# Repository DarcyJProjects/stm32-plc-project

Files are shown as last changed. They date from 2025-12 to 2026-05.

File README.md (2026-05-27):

# Industrial Automation Embedded Controller

### Introduction

This project was a deep dive into 4-layer PCBs, galvanic isolation, strict EMI filtering, and mixed-signal design with the goal to create a robust, industrial-style controller from scratch.

Built around an STM32 Cortex-M4, this embedded controller handles galvanically isolated field I/O using a custom DMA-driven MODBUS RTU stack. It also features a "no-code" automation engine, letting you configure logic remotely via a web panel.

I've implemented several hardware features including an RTC with battery backup, HMI OLED, microSD logging, an EEPROM, efficient multi-stage power distribution & conversion with real time power monitoring, as well as many protection features.

The entire ecosystem - the custom PCB, schematics, firmware, and the web panel - is completely open-source right here, so feel free to look into it and see how it works!

#### Datasheet: Read the full datasheet [here](https://github.com/DarcyJProjects/embedded-controller/blob/main/Documentation/datasheet/datasheet.pdf).

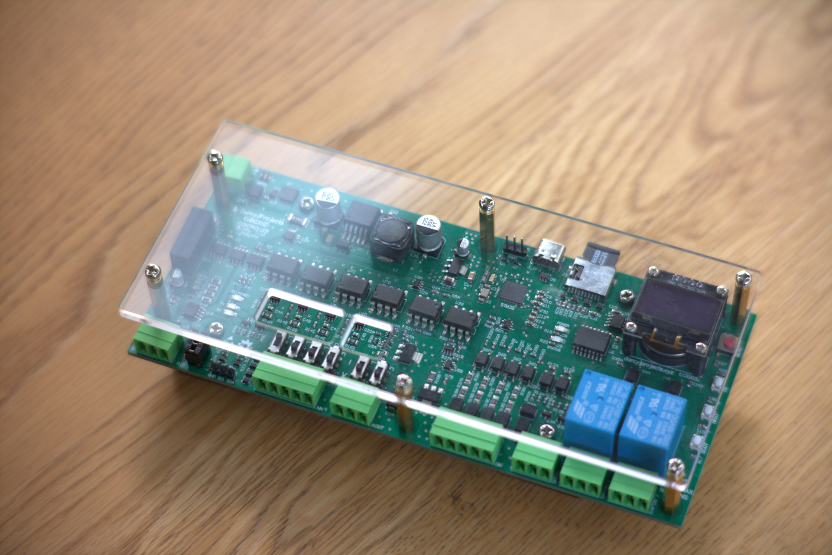
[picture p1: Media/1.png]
IMG: Main


<p>
  This project is open source hardware under the <strong>CERN Open Hardware Licence Version 2 - Strongly Reciprocal (CERN-OHL-S v2)</strong>.
</p>
Open Source Hardware Logo

The editable hardware source files are provided so that the design can be studied, modified, and manufactured in accordance with the licence.

⚖️**Disclaimer:** *This hardware is a personal engineering project created solely for **educational purposes and skill development**. While it explores industrial design techniques, it has not been tested against or certified for any specific industrial standards (e.g., IEC, UL, CE). It is provided ”AS IS” without warranty. For full licence details, design files, and terms of use, please see the **[licence section of this document](#-licence)**.*

---

## 📑 Table of Contents

* 📷 [Demo](#-demo)

* 🎛 [Features and Specifications](#-features-and-specifications)

* ⚡[How It Works](#-how-it-works)

* 🧠 [Why I Built This](#-why-i-built-this)

* 🛠️ [Getting Started](#%EF%B8%8F-getting-started)

* 📂 [Repo Structure](#-repo-structure)

* 📜 [Licence](#-licence)

* ⚠️ [Safety Disclaimer](#-safety-disclaimer)

* 🔗 [Acknowledgements](#-acknowledgements)

* 💬 [Feedback & Contributions](#-feedback--contributions)

---

## 📷 Demo

For the demo, I mounted the controller on a DIN rail and wired it into a small irrigation-style test rig. The goal was to demonstrate as many parts of the board as possible, including relay outputs, digital inputs, analogue voltage signals, 4-20 mA current loops, and MODBUS-based monitoring/control.

Coming soon...

---

## 🎛 Features and Specifications

I tried to pack a wide range of industrial-style hardware and firmware features into this controller so I could learn as much as possible across the realms of PCB design, embedded firmware, power electronics, isolation, and automation protocols.

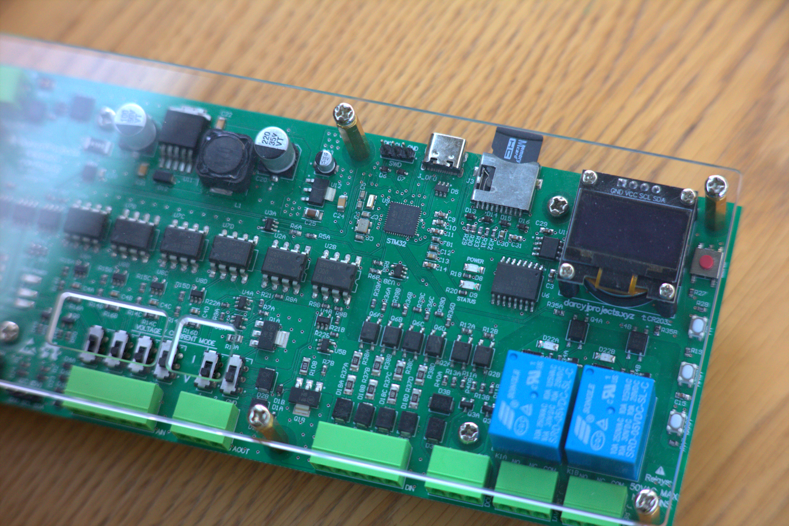
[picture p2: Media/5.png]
IMG: PCB


### **Core Specifications:**

- **Core:** STM32G431 Cortex-M4 MCU running at up to 170 MHz
- **Power input:** 7–28 V DC input range
- **PCB:** Custom 4-layer PCB with separated logic and field domains
- **Protection:** Reverse polarity protection, over-current protection, TVS protection, and ESD protection
- **Isolation:** Galvanic isolation between the logic side and field-side interfaces
- **Memory:** 4 KB EEPROM with CRC-backed configuration and automation rule storage
- **Connectivity:** Isolated RS485 for MODBUS RTU, plus USB-C for DFU flashing and serial debugging
- **Control:** Web panel with custom "no-code" automation rules and MODBUS register access
- **Local interface:** OLED display, tactile buttons, status LEDs, and hardware mode switches, on-board configuration factory reset
- **Expansion:** Isolated I²C header for supported field-side peripherals

### Isolated Field I/O:

- **4x Analogue inputs**
  
  - 12-bit measurement
  - Each configurable for 0–5 Vor 4–20 mA operation

- **2x Analogue outputs**
  
  - 12-bit output
  - Each configurable for 0–5 V voltage output or 4–20 mA current-loop operation

- **4x Digital inputs**
  
  - Designed for 24 V DC signalling

- **2x Digital outputs**
  
  - Low-side sinking outputs for 24 V DC loads

- **2x Relay outputs**
  
  - Intended for ELV switching only
  - Rated in the datasheet for 30 V DC / 50 V AC application limits

- **Isolated I²C expansion header**
  
  - Allows supported external devices to be mapped into the MODBUS register space with custom firmware drivers

### Power:

- Buck Converter for High Efficiency 24 V to 5 V conversion
- Linear Regulator for a clean 3.3 V supply to the MCU
- Switching Isolation Power Supply to power the field side circuitry
- PPTC Fuses, "Ideal Diode" Reverse Polarity Protected Input

### On Board HMI:

- 0.96" OLED display
- 4x tactile buttons for menu navigation, reset, DFU entry, and factory reset
- Status LEDs for power, isolated power, communication, relay state, and general status
- Hardware mode switches for analogue current/voltage configuration

### Overall Block Diagram:

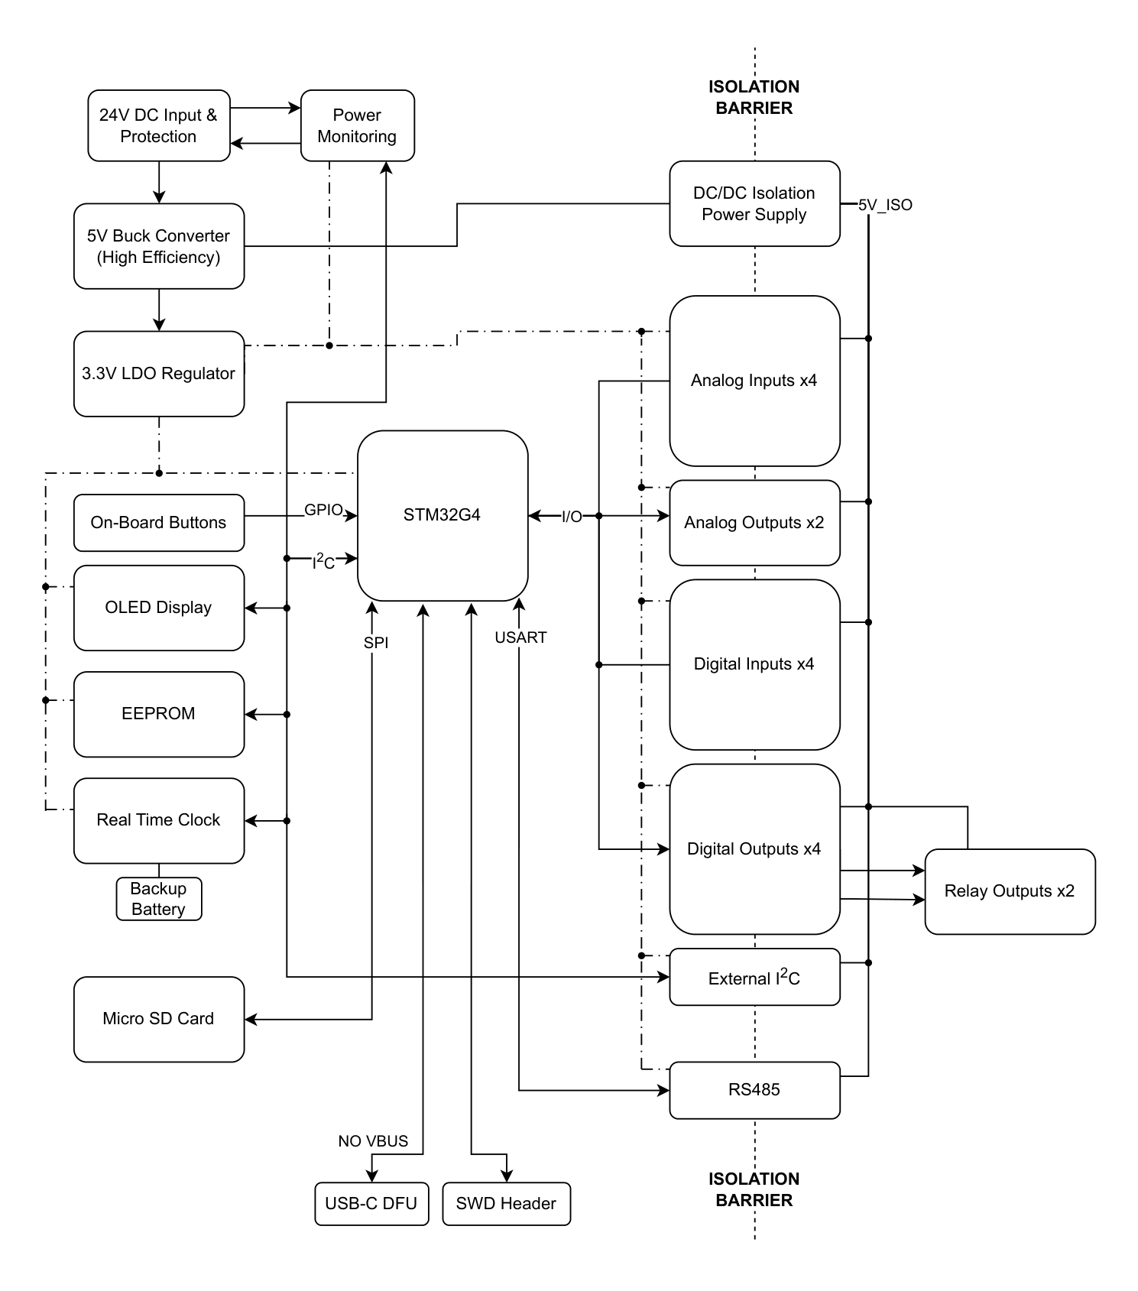
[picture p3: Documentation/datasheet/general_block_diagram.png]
IMG: Block diagram


### Power Supply Block Diagram:

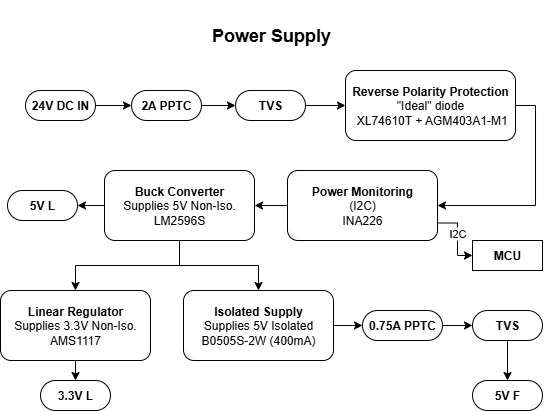
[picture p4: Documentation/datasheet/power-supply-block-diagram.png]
IMG: Power Supply Block Diagram


---

## ⚡ How It Works

The controller is split into two main electrical domains:

1. **Logic Domain:** STM32G4 MCU, EEPROM, OLED, RTC, buttons, USB-C DFU, isolated signals coming from the I/O isolators, etc.

2. **Field Domain:** I/O Inputs and Outputs, Relays, RS485, Isolated I²C expansion header

These two domains are separated by a galvanic isolation barrier. If you look at the PCB, you can actually see a moat separating the two sides copper pours.

The field side is powered through an isolated 5V DC/DC converter, and the signals that cross the barrier use appropriate isolators depending on the interface (capacitive, optical, etc).

### MODBUS register model

The firmware exposes the controller's I/O through a MODBUS register map:

- **Discrete inputs** for digital input states
- **Coils** for digital outputs and relay outputs
- **Input registers** for analogue input readings
- **Holding registers** for analogue output setpoints

There are also **virtual registers**, which can be created dynamically and used as intermediate values in the automation logic. This is useful for when you need to link many rules together for more complex automation logic.

### Custom automation engine

One of the main firmware features is the local automation engine. Instead of reflashing the STM32 every time you want to update its configuration or more importantly its automation logic, rules can be configured directly over MODBUS using custom vendor-defined (that's me!) function codes.

The idea is to make the board behave a little more like a tiny configurable PLC. A rule can read an input, compare a value, update an output, or write to a virtual register. Once configured, the STM32 runs the logic locally.

### Hybrid MODBUS master/slave concept

The firmware is also designed around a hybrid MODBUS architecture allowing the controller to act as both a master and slave at the same time. The controller can report data to an upstream system while also communicating with downstream MODBUS devices.

For instance, [I reverse engineered an RS485 SHT30 sensor](https://darcyjprojects.xyz/index.php/2025/07/08/reverse-engineering-a-cheap-sht30-rs485-modbus-sensor/) used for reading temperature and humidity. By connecting this to the RS485 line of the embedded controller, it can read from the sensor over MODBUS (as a master to the slave sensor) while also reporting information requested back to the web panel (as a slave to the master web panel). 

This was mainly an experiment in building something more flexible than a fixed slave board, while still keeping the system simple enough to understand and debug.

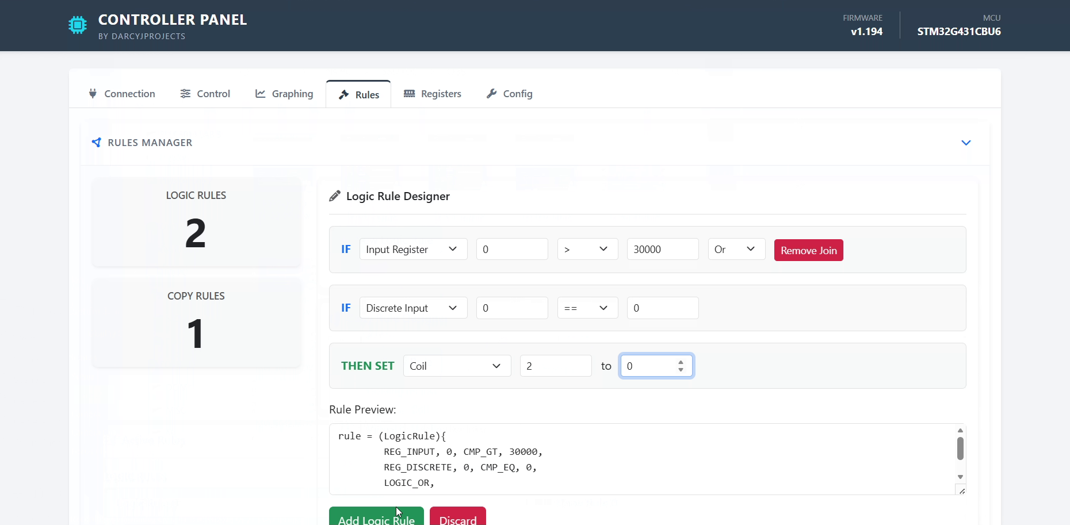
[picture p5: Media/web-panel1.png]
IMG: Web Panel


---

## 🧠 Why I Built This

This project was a major undertaking compared to my earlier electronics projects, integrating mixed signal design, complex isolation barriers, and low level C protocol implementation. I wanted to build something that forced me to deal with more realistic embedded hardware problems, relevant to industrial, mining, manufacturing and remote monitoring environments.

### What I learnt: hardware

- 4-layer PCB design
- Altium Designer workflow
- Mixed-signal PCB layout
- Analogue and digital galvanic isolation
- Isolated power supply design
- 24 V field input and output circuitry
- 4–20 mA current-loop inputs and outputs
- RS485 physical-layer design, termination, and biasing
- Relay output design and low-side switching
- Protection circuitry using PPTC fuses, TVS diodes, and MOSFET-based reverse polarity protection
- Rail-to-rail op-amp circuits for buffering, scaling, and signal conditioning
- Debugging real PCB mistakes using trace cuts, enamel wire, and a lot of patience
- Parasitic impedance and what it does to buck converters!

### **What I learnt: Software**

- STM32CubeIDE and STM32G4 firmware development
- Writing a MODBUS RTU stack from scratch
- Using DMA so communication does not block the CPU
- Building drivers for EEPROMs, RTCs, OLEDs, and other peripherals
- Storing configuration data with CRC checks
- Designing a small rule engine for local automation logic
- Mapping physical and virtual I/O into a MODBUS register model
- Building a Node.js web panel to configure and monitor an embedded device
- How to use LaTeX to write documentation

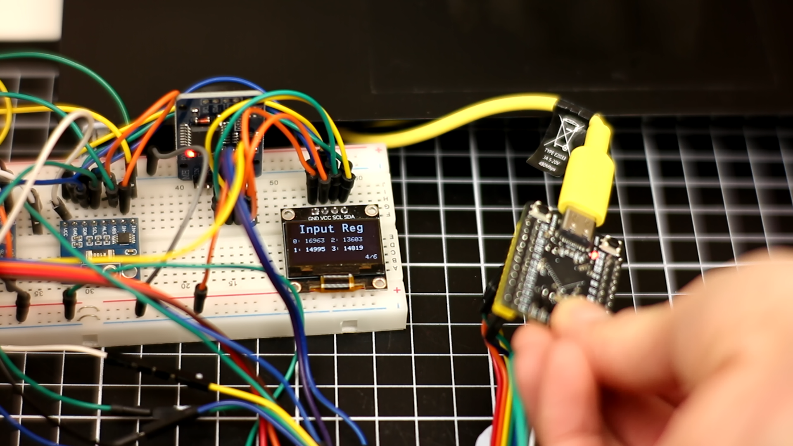
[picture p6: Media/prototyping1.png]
IMG: Prototyping


---

## 🛠️ Getting Started

> **Note:** This project is not a polished commercial product or a beginner-friendly kit. It is a learning project and should be treated carefully, especially when connecting external power supplies, field wiring, or loads.

### Hardware

Before powering the board:

1. Inspect the PCB for solder bridges, assembly mistakes, damaged connectors, or incorrect component values.
2. Check the analogue input/output mode switches before connecting sensors or actuators.
3. Confirm the input supply is within the supported DC range.
4. Use a current-limited bench supply for first power-up.
5. Do not connect mains voltage or safety-critical loads.
6. Check the datasheet before connecting external devices.

### Firmware

The STM32 firmware project is intended to be opened in STM32CubeIDE.

Typical workflow:

1. Open the firmware project
2. Build the project in STM32CubeIDE.
3. Flash the board using USB DFU (hold down BOOT0 and press NRST while powered to enter DFU mode)
4. Connect over serial/MODBUS for debugging or configuration.

### Web panel

The web panel is intended to run locally and communicate with the controller over a USB/serial MODBUS connection.

```bash
cd "Web Panel"
npm install
npm start
```

Then open the local address shown in the terminal in a web browser. You will need an RS485 to USB-Serial converter so that you can select a COM port to communicate with the embedded controller.

---

## 📂 Repo Structure

```text
stm32-plc-project/
├── Documentation/              # Datasheet, drawings
├── Firmware/                   # STM32CubeIDE firmware project
├── Hardware/                   # Altium Designer project: PCB design files, schematics
├── Web Panel/                  # Node.js web configuration panel
├── Media/                      # Photos, renders, screenshots, and demo images
├── LICENCE-CERN-OHL-S-2.0.txt  # CERN-OHL-S v2 licence text for hardware
├── LICENCE-MIT.txt             # MIT licence text for software
└── README.md                   # this file!
```

---

## 📜 Licence

This repository contains both hardware design files and software.

### Hardware

The hardware design files are licenced under the **CERN Open Hardware Licence Version 2 - Strongly Reciprocal (CERN-OHL-S v2)**.

This applies to the PCB design files, schematics, hardware source files, mechanical drawings, and other files required to study, modify, manufacture, and distribute the hardware design.

You are free to:

- **Study** and **modify** the design
- **Make** your own copies
- **Distribute** modified versions, as long as you follow the licence terms

In general, the strongly reciprocal licence means that modified versions of the covered hardware design must also be shared under the same licence, with attribution and source files provided.

For the full legal terms, see [LICENCE-CERN-OHL-S-2.0.txt](https://github.com/DarcyJProjects/embedded-controller/blob/main/LICENCE-CERN-OHL-S-2.0.txt).

### Firmware and Software

Unless otherwise stated, the firmware and software in this repository are licenced under the **MIT Licence**.

This applies to the STM32 firmware and the web configuration panel.

For the full legal terms, see [LICENCE-MIT.txt](https://github.com/DarcyJProjects/embedded-controller/blob/main/LICENCE-MIT.txt).

### Third-Party Code and Resources

Some parts of this project make use of third-party open-source code and resources. These remain under their original licences and are acknowledged in the [Acknowledgements](#-acknowledgements) section.

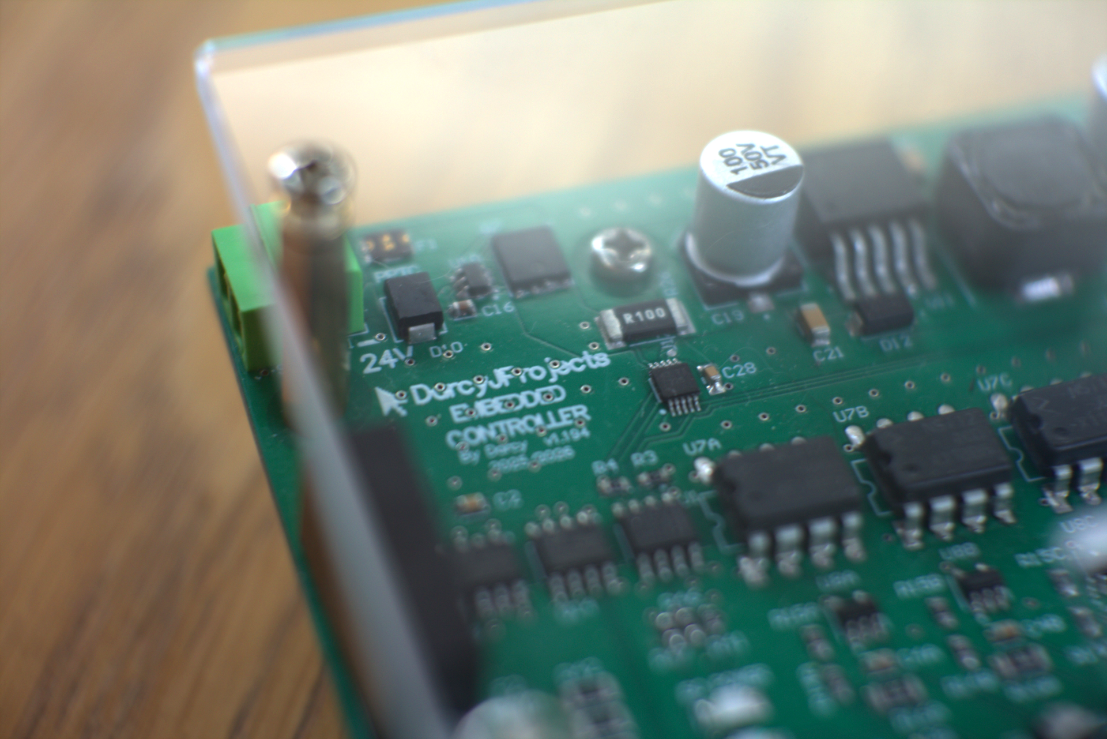
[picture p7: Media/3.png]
IMG: Close up


---

## ⚠️ Safety Disclaimer

This hardware is a personal engineering project created solely for educational purposes, experimentation, and skill development.  

Although it uses industrial-style design techniques, it has **not** been tested, approved, certified, or validated against industrial, safety, EMC, electrical, environmental, functional safety, or regulatory standards, including IEC, UL, CE, RCM, or any similar certification scheme.  

**LIMITATION OF LIABILITY:**

**THIS PROJECT IS PROVIDED "AS IS", WITHOUT WARRANTY OF ANY KIND, EXPRESS OR IMPLIED. TO THE MAXIMUM EXTENT PERMITTED BY LAW, THE COPYRIGHT HOLDER ACCEPTS NO LIABILITY FOR ANY DAMAGE, INJURY, DEATH, LOSS, NON-COMPLIANCE, EQUIPMENT FAILURE, DATA LOSS, BUSINESS INTERRUPTION, OR ANY OTHER ISSUE RESULTING FROM THE USE, MODIFICATION, MANUFACTURE, ASSEMBLY, DISTRIBUTION, OR ATTEMPTED DEPLOYMENT OF THIS DESIGN.**

Do **not** use this project in:  

- real industrial installations  
- safety-critical systems  
- mains-voltage systems  
- life-support, medical, automotive, aviation, mining, or hazardous environments  
- commercial products without proper engineering review, testing, certification, and regulatory approval  
- any system where failure could cause injury, property damage, environmental harm, financial loss, or unsafe operation  

Anyone using, modifying, manufacturing, or testing this design does so entirely at their own risk and is responsible for ensuring compliance with all applicable laws, standards, and safety requirements.

---

## 🔗 Acknowledgements

- The datasheet for this project was created using the [LaTeX Datasheet Template by Petteri Aimonen](https://github.com/PetteriAimonen/latex-datasheet-template), which is licenced under the LPPL-1.3c licence.

- The firmware directly uses the [stm32-ssd1306 OLED display driver by afiskon](https://github.com/afiskon/stm32-ssd1306) for the SSD1306-based OLED display, which is licenced under the MIT licence.

- The MicroSD / FatFS implementation was helped by this tutorial kiwih: [An SD card over SPI using STM32CubeIDE and FatFS](https://01001000.xyz/2020-08-09-Tutorial-STM32CubeIDE-SD-card/).

- Some parts of the firmware were written early in the project while the hardware was still being tested on breadboards. I have tried to acknowledge all external resources used, but if I have missed anything, please let me know and I will be happy to add the appropriate credit.

---

### 💬 Feedback & Contributions

Feel free to fork, share, and build your own!

If you build one, adapt part of the design, or use it to help with one of your own projects, I would love to see it - tag me on [LinkedIn](https://www.linkedin.com/in/darcywdjohnson/).

---

🔧 Darcy @ [www.darcyjprojects.xyz](https://www.darcyjprojects.xyz)

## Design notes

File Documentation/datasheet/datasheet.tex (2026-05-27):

%% STM32 Industrial Controller Datasheet
%% Customized for DarcyJProjects

\documentclass[10pt]{datasheet}

% Standard packages
\usepackage[utf8]{inputenc}
\usepackage[english]{babel}
\usepackage{graphicx} % Needed for inserting photos/block diagrams
\usepackage{tabularx} % Better tables
\usepackage{float} % Keep things where they should be
\usepackage{enumitem}
% Allows absolute positioning of text (for the version stamp)
\usepackage[absolute]{textpos}

% Document Meta-Data
\title{STM32G4 Embedded Industrial Controller}
\author{DarcyJProjects}
\date{February 2026}
\revision{Rev 1.0}
\companylogo{
    % Negative value (-0.2\height) pushes the image DOWN by 20% of its own height
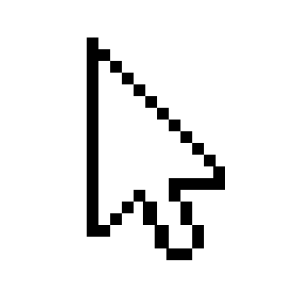
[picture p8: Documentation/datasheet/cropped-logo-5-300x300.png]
    \raisebox{-0.22\height}{}
    \hspace{0cm} % Adds a small gap between logo and text
    \Huge \textbf{DarcyJProjects}
} % Simple text logo for now

\begin{document}

% --- HARDWARE VERSION STAMP ---
% {5cm} is the width of the box
% (15cm, 1cm) are the X, Y coordinates from the top-left of the page
% Adjust 15cm to move it Left/Right, Adjust 1cm to move it Up/Down
\begin{textblock*}{5cm}(15cm, 2.5cm) 
    \raggedleft % Align text to the right
    \small 
    \textbf{Hardware Ver:} v1.194
\end{textblock*}

\maketitle

\section{Features}
\begin{itemize}[leftmargin=*, itemsep=2pt, topsep=0pt]
    \item \textbf{Core:} STM32G431 Cortex-M4 MCU @ 170MHz
    \item \textbf{Power:} 12V-28V DC (Rev. Polarity, OCP, TVS)
    \item \textbf{Isolation \& Protection:} 1 kV Galvanic Isolation, ESD Protection up to 30 kV
    
    % CONDENSING STRATEGY: Use a paragraph style for the big lists.
    % Notice how we just list them with commas instead of new bullets.
    \item \textbf{Field I/O (All Isolated):}
    4x Analog Inputs (12-bit, 4-20mA/0-5V),
    2x Analog Outputs (12-bit, 4-20mA/0-5V),
    4x Digital Inputs (24V),
    2x Digital Outputs (24V),
    2x Relays (10A / 30VDC, ELV 50VAC),
    Isolated $I^2$C Header.

    \item \textbf{On-Board HMI:} 
    0.96" OLED Display, 
    4x Tactile Buttons, 
    5x Status LEDs, 
    6x Hardware Mode Switches (Analog Current/Voltage Mode Configuration).

    \item \textbf{Memory:} 4KB EEPROM with CRC (Stores Configuration \& Automation Rules)

    \item \textbf{Connectivity:}
    Isolated RS485 (MODBUS RTU Master/Slave);
    USB-C (DFU Flashing \& Serial Debug)

    \item \textbf{Reliability:} 4-Layer PCB with Isolation Barrier, PPTC Fuses, TVS Protection.
    \item \textbf{Control:} Web Panel with custom "No-Code" automation engine; Full MODBUS RTU support for SCADA integration.
\end{itemize}

\section{Example Demonstration Use Cases}
\begin{itemize}[leftmargin=*, itemsep=2pt, topsep=0pt]
    \item \textbf{Industrial Sensor Node:} Aggregation of voltage or 4-20mA process signals (pressure, flow, level) to MODBUS RTU.
    \item \textbf{Distributed I/O Expansion:} Cost-effective relay control and status monitoring for existing SCADA networks.
    \item \textbf{Hybrid Edge Controller:} Autonomous control of downstream MODBUS slaves (e.g., VFDs, remote sensors) while simultaneously reporting status to an upstream SCADA system.
    \item \textbf{Embedded Logic Prototyping:} Development platform for custom control loops and automation logic using the STM32G4.
\end{itemize}

% --- SECTION 3: VISUALS ---
% \vfill\break % Force column break so images sit nicely on the right

\begin{figure}[h]
    \centering
    % REPLACE 'example-image' with your actual filename (e.g., board_photo.png)
    % You can upload files to Overleaf using the upload button on the left.
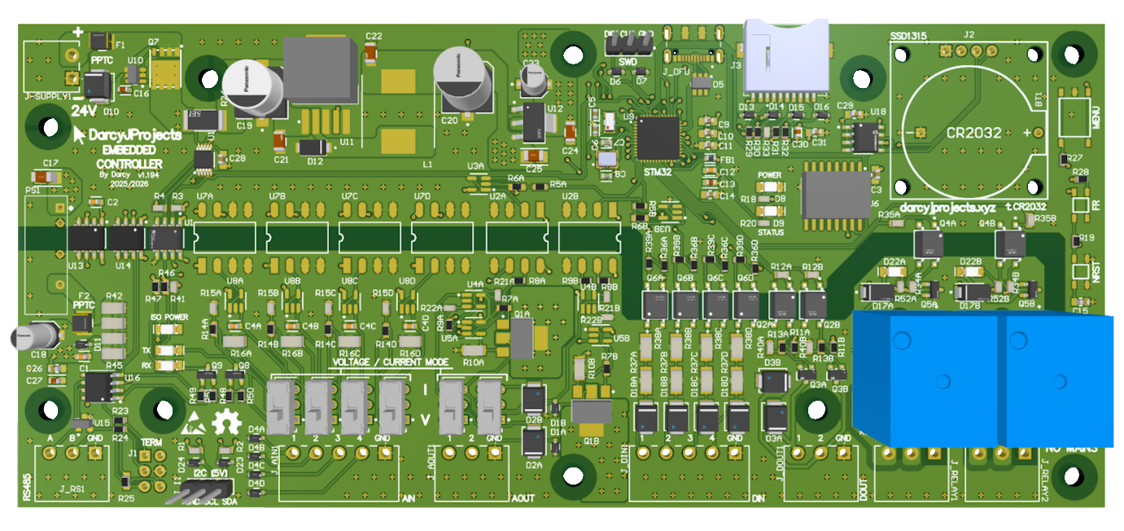
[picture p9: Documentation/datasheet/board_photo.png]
     
    \caption{Board Top View}
\end{figure}

%\begin{figure}[h]
%    \centering
    % REPLACE 'example-image' with your block diagram
%    \includegraphics[width=0.8\linewidth]{example-image}
%    \caption{System Block Diagram}
%\end{figure}

% --- SECTION 2: DESCRIPTION ---
\section{General Description}
The \textbf{DJP-G431-EIC} is an educational embedded controller inspired by industrial I/O and PLC-style design practices. Built around the high-performance STM32G4 series, it features a high-efficiency 24V buck converter and \textbf{full galvanic isolation} on all field interfaces, ensuring system stability in noisy environments.

Unique to this controller is a \textbf{Hybrid Master-Slave} configuration handled by a custom \textbf{DMA-driven MODBUS RTU stack}. This allows the board to autonomously control downstream devices while simultaneously reporting to an upstream SCADA system or Web Panel. An on-board OLED display with burn-in protection provides local feedback on system status and configuration.

For logic control, the board natively supports a custom \textbf{Rule-Based Automation Engine}. This system is fully programmable over MODBUS using the Node.js Web Panel or manually with the vendor-defined functions, allowing for remote "No-Code" logic configuration without the need to reflash firmware.

% The "Research Purpose" Qualifier
\vspace{1em}
\begin{center}
\fbox{\parbox{0.95\linewidth}{
    \centering
    \scriptsize
    \textit{\textbf{DISCLAIMER:} This hardware is a personal engineering project created solely for \textbf{educational purposes and skill development}. While it explores industrial design techniques, it has \textbf{not} been tested against or certified for any specific industrial standards (e.g., IEC, UL, CE). It is provided "AS IS" without warranty.}
    
    \vspace{0.3em} % Tiny gap
    \textit{For full licence details, design files, and terms of use, please refer to the project repository at \textbf{github.com/DarcyJProjects}.}
}}
\end{center}

% Switch to single column for the big data tables
\onecolumn
\clearpage
\raggedbottom

\section{System Architecture}
The internal architecture of the DJP-G431-EIC is divided into two galvanically isolated domains: the \textbf{Logic Domain} (MCU, Main Power Supply, etc.) and the \textbf{Field Domain} (Field I/O, RS485, etc.). 

The following block diagram illustrates the power distribution path, isolation barriers, and internal peripheral connections. A physical separation width is maintained along the isolation barrier on the PCB utilising different electrical isolation methods (capacitive, optical, etc.), depending on the signal.

% BLOCK DIAGRAM
\begin{figure}[H]
    \centering
    % Reduced width slightly to 0.85 to ensure everything fits
     
    \caption{System Block Diagram showing Power Architecture and Galvanic Isolation.}
    \label{fig:general_block_diagram}
\end{figure}

\section{Electrical Specifications}
Conditions: $V_{IN} = 24V$, $T_A = 25^{\circ}C$ unless otherwise noted.

\begin{table}[H]
\caption{Isolation \& Protection Characteristics}
\begin{tabularx}{\textwidth}{l | c | c | X}
    \thickhline
    \textbf{Parameter} & \textbf{Symbol} & \textbf{Value} & \textbf{Conditions} \\
    \hline
    \multicolumn{4}{l}{\textit{\textbf{Galvanic Isolation}}} \\
    \hline
    \textbf{System Isolation} & $V_{ISO\_SYS}$ & \textbf{1000 VDC} & \textbf{Limited by DC/DC Power Supply} \\
    Data Channel Rating & $V_{ISO\_DAT}$ & 3750 Vrms & Component Rating (Isolators Only) \\
    Isolation Capacitance & $C_{ISO}$ & $\sim$40 pF & Barrier Capacitance (Typical) \\
    \hline
    \multicolumn{4}{l}{\textit{\textbf{ESD Protection}}} \\
    \hline
    \textbf{General I/O \& Power} & $V_{ESD\_GEN}$ & $\pm$30 kV & \textbf{IEC 61000-4-2} (Air \& Contact) \\
    \multicolumn{4}{l}{\textit{\footnotesize (Includes: Power In, Digital I/O, Analog I/O, SD Card, SWD)}} \\
    \hline
    \textbf{Comm. Interfaces} & $V_{ESD\_COM}$ & $\pm$15 kV & \textbf{IEC 61000-4-2} (Air) \\
     & & $\pm$8 kV & \textbf{IEC 61000-4-2} (Contact) \\
    \multicolumn{4}{l}{\textit{\footnotesize (Includes: RS485, USB DFU)}} \\
    \hline
    \textbf{I2C Expansion} & $V_{ESD\_I2C}$ & $\pm$4 kV & \textbf{HBM} (ISO1540 Native Rating) \\
    \hline
    \multicolumn{4}{l}{\textit{\textbf{EFT Immunity}}} \\
    \hline
    Power \& Field I/O & $V_{EFT}$ & 4 kV & \textbf{IEC 61000-4-4} (Level 4) \\
    \thickhline
\end{tabularx}
\end{table}

\begin{table}[H]
\caption{Over-Current Protection (PPTC Resettable Fuses)}
\begin{tabularx}{\textwidth}{l | c | c | c | X}
    \thickhline
    \textbf{Protected Rail} & \textbf{Hold} ($I_{HOLD}$) & \textbf{Trip} ($I_{TRIP}$) & \textbf{Max V} & \textbf{Notes} \\
    \hline
    Main Power Input ($V_{IN}$) & 2 A & $\sim$2x the hold  & 30 V & Protects entire board \\
    5V\_ISO & 750 mA & $\sim$2x the hold & 6 V & Protects B0505S isolated DC/DC \\
    \thickhline
\end{tabularx}
\begin{tablenotes}
\footnotesize
\item \textbf{Note:} Fuses are self-resetting. To reset a tripped fuse, remove the fault and cycle power for $>10$ seconds.
\end{tablenotes}
\end{table}

\begin{table}[h]
\begin{threeparttable}
\caption{DC Characteristics}
\begin{tabularx}{\textwidth}{l | c | c c c | c | X}
    \thickhline
    \textbf{Parameter} & \textbf{Symbol} & \textbf{Min.} & \textbf{Typ.} & \textbf{Max.} & \textbf{Unit} & \textbf{Comments} \\
    \hline
    \multicolumn{7}{l}{\textbf{Power Supply}} \\
    \hline
    Supply Voltage      & $V_{IN}$   & 12  & 24  & 28  & V  & Operating Range \\
    Supply Current      & $I_{IN}$   & -   & 90  & 150 & mA & Idle vs. Relays Active @ $V_{IN}$=24 V \\
    \hline
    \multicolumn{7}{l}{\textbf{Digital Inputs}} \\
    \hline
    Input Voltage High  & $V_{IH}$   & 1.5  & 24  & 28  & V  & Logic "1" Threshold \\
    Input Voltage Low   & $V_{IL}$   & 0  & 0   & 1.3  & V  & Logic "0" Threshold \\
    Input Current       & $I_{DIN}$  & -   & 11.4   & 14.9  & mA & @ 24V (Typ) / 28V (Max) \\
    \hline
    \multicolumn{7}{l}{\textbf{Digital Outputs}} \\
    \hline
    Cont. Sink Current  & $I_{DOUT}$ & -   & -   & 500 & mA & \textbf{Sinking} Per Channel \\
    Output Voltage Drop & $V_{DROP}$ & -   & 10 & 16 & mV  & @ 500mA Load \\
    \hline
    \multicolumn{7}{l}{\textbf{Digital Outputs (Relays)}} \\
    \hline
    Switching Voltage (DC)   & $V_{SW}$   & -   & 24  & 30 & V  & DC Voltage  \\
    Switching Voltage (AC)   & $V_{SW}$   & -   & 24  & 50 & VAC  & AC Voltage  \\
    Switching Current   & $I_{SW}$   & -   & -   & 10  & A  & Max Resistive Load \\
    Contact Resistance  & $R_{CONT}$ & -   & - & 100   & m$\Omega$ & Initial value \\
    \hline
    \multicolumn{7}{l}{\textbf{Analog Inputs (12-Bit)}} \\
    \hline
    Input Impedance (V) & $R_{IN(V)}$& - & 49   & -   & k$\Omega$ & 0-5V Mode \\
    Input Impedance (I) & $R_{IN(I)}$& -   & 10 & -   & $\Omega$ & 4-20mA Mode \\
    \hline
    \multicolumn{7}{l}{\textbf{Analog Outputs (12-Bit)}} \\
    \hline
    Output Voltage      & $V_{OUT}$  & 0   & -   & 5   & V  & 0-5V Mode -- \textbf{Sourcing} (Active) \\
    % Source Current      & $I_{SRC}$  & -   & -   & XX  & mA & 0-5V Mode -- Max drive \\
    \hline
    % Current Sink Range\tnote{1}  & $I_{SNK}$  & X   & -   & XX  & mA & 4-20mA Mode -- \textbf{Sinking} (Passive) \\
    Max Loop Voltage\tnote{3}    & $V_{LOOP}$ & 12  & 24  & 30  & V  & 4-20mA Mode -- Ext. Loop Supply \\
    Max Loop Resistance & $R_{LOOP}$ & 300 & 900 & 1075 & $\Omega$ & @ 12V / 24V / 30V Loop Voltage \\
    \hline
    \multicolumn{7}{l}{\textbf{RS485 Interface}} \\
    \hline
    Bus Voltage Range\tnote{2}   & $V_{BUS}$  & -7  & -   & 12  & V  & Common Mode Range (A/B) \\
    Input Impedance     & $R_{IN}$   & 12  & -   & -   & k$\Omega$ & 1 Unit Load (Max 32 Nodes) \\
    \hline
    \multicolumn{7}{l}{\textbf{External $I^2C$ Expansion Header}} \\
    \hline
    Field Signal Voltages\tnote{2}      & $V_{SDA2}, V_{SCL2}$  & 0 & - & 5.0 & V  & Field Signal Voltages \\
    Pull-Up Resistance  & $R_{PU}$   & 4.4   & 4.7 & 5.0   & k$\Omega$ & On-Board $I^2C$ Field Pull-ups \\
    \thickhline
\end{tabularx}
\begin{tablenotes}
\footnotesize
% The \tnote{1} connects to the superscript 1 in the table
\item[1] \textbf{Note:} The exact 4mA and 20mA setpoints are determined by firmware calibration values. Improper configuration may result in output currents deviating from these nominal targets (e.g. $<4$mA or $>20$mA).
\item[2] Relative to 5V\_ISO\_GND (the GND pin in the field header or connector).
\item[3] \textbf{Important:} The maximum loop voltage drops significantly as the ambient temperature rises. See Absolute Maximum Ratings.
\end{tablenotes}
\end{threeparttable}
\end{table}

\clearpage

\section{Absolute Maximum Ratings}
\begin{table}[H]
\caption{Stress Ratings}
\begin{tabularx}{\textwidth}{l | c | c c | c | X}
    \thickhline
    \textbf{Parameter} & \textbf{Symbol} & \textbf{Min.} & \textbf{Max.} & \textbf{Unit} & \textbf{Comments} \\
    \hline
    \multicolumn{6}{l}{\textbf{Power}} \\
    \hline
    Input Voltage       & $V_{IN\_MAX}$  & 7 & 30 & V & Continuous (Limited by Input PPTC \& TVS) \\
    Max Total Current   & $I_{IN\_MAX}$  & - & 2 & A & Limited by Input PPTC \\
    \hline
    \multicolumn{6}{l}{\textbf{Digital I/O}} \\
    \hline
    DIN Voltage         & $V_{DIN\_MAX}$ & - & 30 & V & Continuous (Thermal Limit of Series Resistors)\\
    \hline
    DOUT Sink Current   & $I_{DOUT\_MAX}$ & - & 3 & A & Continuous (Per Channel) @ $T_A = 85^{\circ}C$\\
    Relay Voltage       & $V_{SW\_MAX(DC)}$ & - & 30 & V & Max DC Contact Switching Voltage \\
    Relay Voltage       & $V_{SW\_MAX(AC)}$ & -  & 50 & VAC & Max AC Contact Switching Voltage \\
    Relay Current       & $I_{REL\_MAX}$ & - & 10 & A & Resistive Load \\
    \hline
    \multicolumn{6}{l}{\textbf{Analog I/O}} \\
    \hline
    AIN Voltage (V-Mode)& $V_{AIN\_MAX(V)}$ & -   & \textbf{5.5} & V & \textbf{Risk of Damage!} (Do not connect 24V) | Continuous (Limited by Input TVS)\\
    AIN Current (I-Mode)& $I_{AIN\_MAX(I)}$ & -   & 140 & mA & Max Loop Current (Shunt Resistor Limit) \\
    \hline
    AOUT Voltage (V-Mode)& $V_{AOUT\_MAX(V)}$ & - & \textbf{5.3} & V & \textbf{Risk of Damage!} (Do not connect 24V) | Max External Voltage applied to pin \\
    AOUT Voltage (I-Mode)& $V_{AOUT\_MAX(I)}$ & - & 26 & V & Max External Loop Voltage (Open Collector) @ $T_A = 85^{\circ}C$ \\
    \hline
    \multicolumn{6}{l}{\textbf{Communication Interfaces}} \\
    \hline
    RS485 Bus Voltage In   & $V_{485\_IN\_ABS}$ & -8 & +12.5 & V & Max voltage on A/B pins before damage \\
    RS485 Bus Voltage Out   & $V_{485\_OUT\_ABS}$ & -8 & +12.5 & V & Max voltage from driver to A/B pins \\
    I2C Pin Voltage     & $V_{I2C\_ABS}$ & -0.5 & 5.5 & V & Max voltages on SDA/SCL \\
    \hline
    %\multicolumn{6}{l}{\textbf{Environmental}} \\
    %\hline
    %Storage Temp.       & $T_{STG}$      & -XX & +XX & $^{\circ}$C & Estimation\\
    %Operating Temp.     & $T_{OP}$       & -XX & +XX & $^{\circ}$C & Estimation \\
    %\thickhline
\end{tabularx}
\end{table}

\clearpage

\section{MODBUS Register Map}
% \vspace{-4em} % Pulls the table up by one line height
\begin{table}[H]
\small
\begin{threeparttable}
\caption{Complete Register Map}
\begin{tabularx}{\textwidth}{c | l | c | c | X}
    \thickhline
    \textbf{Addr} & \textbf{Name} & \textbf{Type} & \textbf{Access} & \textbf{Description} \\
    \hline
    \multicolumn{5}{l}{\textit{\textbf{Discrete Inputs (Digital Inputs)}}} \\
    \hline
    0 & DIN\_1 & Bool & R & Digital Input Channel 1 \\
    1 & DIN\_2 & Bool & R & Digital Input Channel 2 \\
    2 & DIN\_3 & Bool & R & Digital Input Channel 3 \\
    3 & DIN\_4 & Bool & R & Digital Input Channel 4 \\
    \hline
    \multicolumn{5}{l}{\textit{\textbf{Coils (Digital Outputs \& Relays)}}} \\
    \hline
    0 & DOUT\_1 & Bool & R/W & Digital Output 1 \\
    1 & DOUT\_2 & Bool & R/W & Digital Output 2 \\
    2 & RELAY\_1 & Bool & R/W & Relay Output 1 \\
    3 & RELAY\_2 & Bool & R/W & Relay Output 2 \\
    \hline
    \multicolumn{5}{l}{\textit{\textbf{Input Registers (Analog Inputs)}}} \\
    \hline
    0 & AIN\_1 & uint16 & R & Analog Input 1 Raw Value \\
    1 & AIN\_2 & uint16 & R & Analog Input 2 Raw Value \\
    2 & AIN\_3 & uint16 & R & Analog Input 3 Raw Value \\
    3 & AIN\_4 & uint16 & R & Analog Input 4 Raw Value \\
    \hline
    \multicolumn{5}{l}{\textit{\textbf{Holding Registers (Analog Outputs)}}} \\
    \hline
    0 & AOUT\_1 & uint16 & R/W & Analog Output 1 Setpoint (0-65535) \\
    1 & AOUT\_2 & uint16 & R/W & Analog Output 2 Setpoint (0-65535) \\
    \thickhline
\end{tabularx}
\begin{tablenotes}
\footnotesize
\item \textbf{Access Key:} R = Read Only, R/W = Read/Write. 
\item \textbf{Function Codes:} Discrete (0x02), Coils (0x01/0x05/0x15), Inputs (0x04), Holding (0x03/0x06/0x16).
\end{tablenotes}
\end{threeparttable}
\end{table}

\subsection{Virtual Registers}
Virtual Registers can be created dynamically to serve as intermediate variables within the automation logic (e.g., linking rules where the 2-condition limit per rule is exceeded).
\begin{itemize}
    \item \textbf{Addressing:} Virtual registers are automatically mapped starting at the address \textit{after} the last physical channel.
    \item \textit{Example:} If the last physical coil is Address 3, the first Virtual Coil will be \textbf{Address 4}.
\end{itemize}

Since Virtual Registers are defined with specific Modbus data types, they can be fully accessed (Read/Write) using standard Modbus function codes.

\clearpage

\subsection{External Expansion ($I^2C$)}
The isolated 5V $I^2C$ header allows external peripherals to be mapped to MODBUS registers. On-board field side 5V\_ISO pull-up resistors (4.7 k$\Omega$) are installed on SCL and SDA so only 5 V-tolerant $I^2C$ devices should be connected directly. Lower-voltage devices may require an external level shifter, such as a PCA9306.
\vspace{1em} \\
\textit{\textbf{Note:} Unlike the Rule Engine, adding new $I^2C$ devices requires custom read/write drivers and a \textbf{firmware update}. Reference implementations for common sensors can be found in the project source code.}

\subsection{Vendor Defined Function Codes}
These proprietary function codes provide access to specialized device capabilities, including the internal logic engine and virtual register management, that are not covered by standard MODBUS definitions.
\textbf{Range:} 0x65--0x73 (Firmware Defined)
\begin{table}[H]
\begin{tabularx}{\textwidth}{c | l | X}
    \thickhline
    \textbf{Code} & \textbf{Name} & \textbf{Description} \\
    \hline
    0x65 & ADD\_RULE & Defines a new automation rule \\
    0x66 & GET\_RULE\_COUNT & Returns the number of automation rules \\
    0x67 & GET\_RULE & Returns the requested automation rule configuration \\
    0x68 & DELETE\_RULE & Deletes the requested automation rule \\
    0x69 & ADD\_VIRTUAL\_REG & Defines a new virtual register \\
    0x6A & READ\_VIRTUAL\_REG & Returns the value of the requested virtual register \\
    0x6B & WRITE\_VIRTUAL\_REG & Write the specified value to the requested virtual register \\
    0x6C & GET\_VIRTUAL\_REG\_COUNT & Returns the number of virtual registers \\
    0x6D & CLEAR\_VIRTUAL\_REG & Deletes all virtual registers. Warning: Do not execute if there are \textbf{any} rules that reference \textbf{any} virtual registers. \\
    0x6E & SET\_RTC & Sets the RTC date and time \\
    0x6F & SET\_HOLDING\_REG\_MODE & Sets the requested holding register to the specified mode (current/voltage) \\
    0x70 & SET\_INPUT\_REG\_MODE & Sets the requested input register to the specified mode (current/voltage) \\
    0x71 & GET\_REG\_MODE & Returns the mode (current/voltage) of the requested register (holding/input) \\
    0x72 & SET\_EMERGENCY\_STOP & Sets the E-STOP button configuration \\
    0x73 & FACTORY\_RESET & Performs a factory reset, resetting the on-board EEPROM to default values \\
    \thickhline
\end{tabularx}
\end{table}

\textbf{Note:} These function codes are firmware-specific and should not be considered MODBUS-standard or interoperable with other devices.

\section{User Interface}

\subsection{Button Functions}
The board features 4 tactile buttons for menu interaction, system recovery, and boot control.

\begin{table}[h]
\begin{tabularx}{\textwidth}{l | l | X}
    \thickhline
    \textbf{Button} & \textbf{Function} & \textbf{Description} \\
    \hline
    \textbf{MENU} & Navigation & Short Press: Next Menu Screen \\
    \textbf{NRST} & System Reset & Short Press: Hardware Reset (Reboots MCU) \\
    \hline
    \textbf{BOOT0 + NRST} & DFU Mode & Hold BOOT0 and short press NRST to enter DFU mode. OLED should indicate that DFU mode has been entered. \\
    \textbf{FR + NRST} & Factory Reset & Hold FR and short press NRST to restore default configuration options on the EEPROM. Further button press instructions will be provided on the OLED. \\
    \textbf{MENU + NRST} & Skip Boot Animations & Hold MENU and short press NRST to skip boot animations when starting. Useful for quick tests during firmware development. \\
     \thickhline
\end{tabularx}
\end{table}

\subsection{LED Indicators}
\begin{table}[H]
\begin{tabularx}{\textwidth}{l | c | X}
    \thickhline
    \textbf{Name} & \textbf{Color} & \textbf{Indication} \\
    \hline
    \textbf{PWR} & Green & 3.3V Logic Domain Power Active \\
    \textbf{STATUS} & Red & General Status Indicator \\
    \textbf{ISO\_PWR} & Green & 5V Isolated Field Domain Power Active \\
    \textbf{RX/TX} & Blue & Modbus RS485 Data Traffic \\
    \textbf{REL1 / REL2} & Red & Relay Coil Energized (Output Active) \\
    \thickhline
\end{tabularx}
\end{table}

\subsection{RS485 Bus Configuration}
The isolated RS485 interface features a 6-pin jumper header (JP\_RS485) to enable line termination and failsafe biasing. These should be configured based on the device's position in the network.

\vspace{0.5em}

\noindent
\begin{minipage}{0.35\textwidth}
    \centering
    \textbf{Jumper Map (Top View)} \\
    \vspace{0.5em}
    % This grid mimics the physical 2x3 header on your PCB
    \begin{tabular}{|c|c|}
        \hline
        \footnotesize \textbf{1} (A) & \footnotesize \textbf{2} (PULL\_UP) \\
        \hline
        \footnotesize \textbf{3} (B) & \footnotesize \textbf{4} (PULL\_DOWN) \\
        \hline
        \footnotesize \textbf{5} (A) & \footnotesize \textbf{6} (TERM. TO B) \\
        \hline
    \end{tabular}
    \\ \vspace{0.5em}
    \footnotesize \textit{Bridge adjacent pins to enable.}
\end{minipage}%
\hfill
\begin{minipage}{0.6\textwidth}
    \textbf{Configuration Settings:}
    \begin{itemize}[noitemsep, leftmargin=1.5em, topsep=0pt]
        \item \textbf{Bias High (Pins 1-2):} Pulls Line A to 5V\_ISO. \textit{Keeps bus logic "1" during idle.}
        \item \textbf{Bias Low (Pins 3-4):} Pulls Line B to 5V\_ISO\_GND. \textit{Keeps bus logic "0" during idle.}
        \item \textbf{Termination (Pins 5-6):} Connects a $120\Omega$ resistor across lines A and B. \textit{Enable only if this device is at the physical end of the bus cable.}
    \end{itemize}
\end{minipage}

\vspace{0.5em}
\noindent \textit{\footnotesize \textbf{Note:} Failsafe biasing (Pins 1-4) is recommended to prevent noise interpretation when the bus is idle, but ensure only ONE device on the bus provides biasing (usually the Master).}

\clearpage

\section{Software Ecosystem}
The DJP-G431-EIC is supported by a comprehensive software suite:
\begin{itemize}
    \item \textbf{Web Configuration Panel:} A Node.js-based dashboard connecting via the USB-Serial bridge. Allows for real-time monitoring of all registers, hardware configuration, and "No-Code" logic automation; all over MODBUS RTU.
    \item \textbf{Automation Engine:} Custom logic engine supporting drop-down based "If-This-Then-That" rules, executed locally on the STM32, programmed over MODBUS vendor functions. A single rule can include up to two conditions, with virtual registers provided as memory to link several rules (\textgreater 2) together.
\end{itemize}

\section{Mechanical \& Installation}

\begin{figure}[h]
    \centering
    % width=1.0\linewidth ensures it fills the column width while maintaining aspect ratio
     
    \caption{Mechanical Dimensions (Units: mm).}
\end{figure}

\clearpage
\section{Safety Disclaimer}

This hardware is a personal engineering project created solely for educational purposes, experimentation, and skill development.

Although it uses industrial-style design techniques, it has \textbf{not} been tested, approved, certified, or validated against industrial, safety, EMC, electrical, environmental, functional safety, or regulatory standards, including IEC, UL, CE, RCM, or any similar certification scheme.

\vspace{1em}

\noindent\textbf{LIMITATION OF LIABILITY:}

\vspace{0.5em}

\noindent\textbf{THIS PROJECT IS PROVIDED ``AS IS'', WITHOUT WARRANTY OF ANY KIND, EXPRESS OR IMPLIED. TO THE MAXIMUM EXTENT PERMITTED BY LAW, THE COPYRIGHT HOLDER ACCEPTS NO LIABILITY FOR ANY DAMAGE, INJURY, DEATH, LOSS, NON-COMPLIANCE, EQUIPMENT FAILURE, DATA LOSS, BUSINESS INTERRUPTION, OR ANY OTHER ISSUE RESULTING FROM THE USE, MODIFICATION, MANUFACTURE, ASSEMBLY, DISTRIBUTION, OR ATTEMPTED DEPLOYMENT OF THIS DESIGN.}

\vspace{1em}

\noindent Do \textbf{not} use this project in:

\begin{itemize}[leftmargin=*, itemsep=2pt, topsep=4pt]
    \item real industrial installations
    \item safety-critical systems
    \item mains-voltage systems
    \item life-support, medical, automotive, aviation, mining, or hazardous environments
    \item commercial products without proper engineering review, testing, certification, and regulatory approval
    \item any system where failure could cause injury, property damage, environmental harm, financial loss, or unsafe operation
\end{itemize}

Anyone using, modifying, manufacturing, or testing this design does so entirely at their own risk and is responsible for ensuring compliance with all applicable laws, standards, and safety requirements.

\end{document}

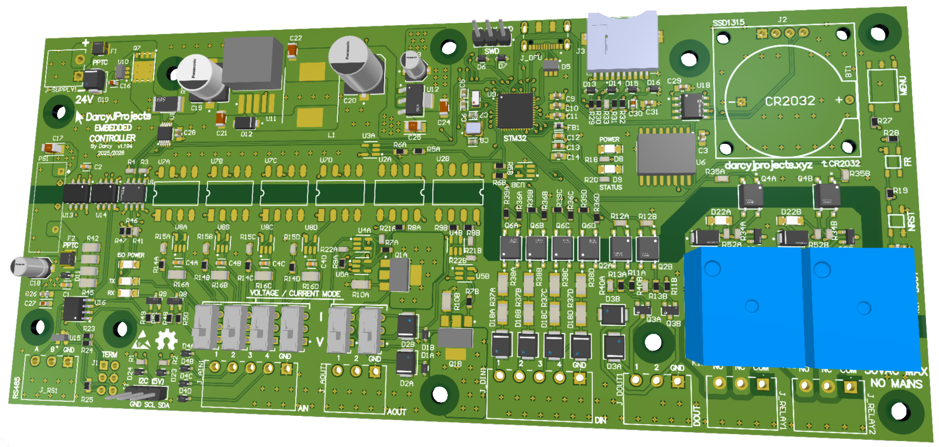
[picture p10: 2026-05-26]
Media/embedded-controller-render-transparent.png

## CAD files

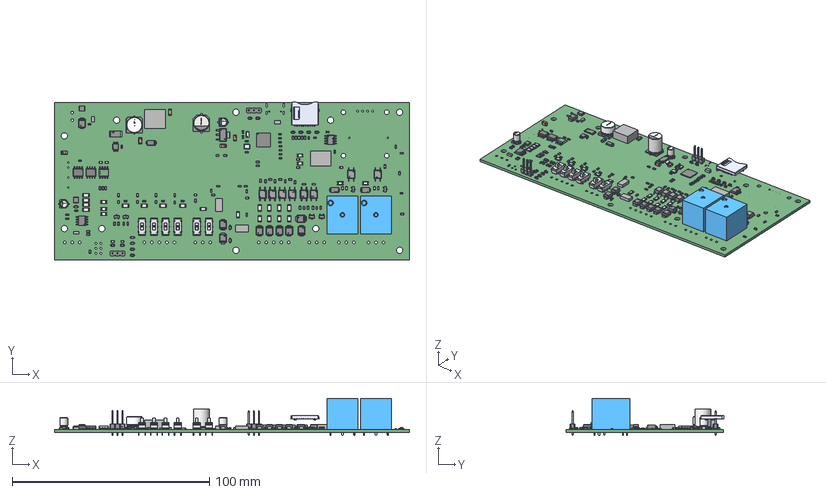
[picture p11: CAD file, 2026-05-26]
Hardware/Main.step
180.0 x 80.3 x 18.9 mm
Extruded x 139
name x 7
Nexperia Logo x 15
Switch_C&K_JS202011CQN_eec x 6
housing x 7
cover x 7
base x 15
marking x 7
Mid_Body x 43
Mark x 43
pins x 6
part number & logo x 4
Cap_Panasonic_EEEFK1E100R_eec x 12
MULTICOMP PRO Logo x 2
direction _Mark x 2
Vishay logo x 9
Vishay logo - Copy x 9
Base
Crystal
NDK logo
logo x 6
BODY_MUB10A
LEAD_MUB10A x 10
Leader x 16
Notch 2
IC_BODY
circle
IC_LEG x 4
IC_LEG_MIR5 x 4
Texas Instruments
terminals x 2
top
Alpha & Omega Logo x 2
header x 6
side x 6
Murata
Bourns Inc. MF-USMF020-2 1 - Copy x 2
Bourns Inc. MF-USMF020-2 1 x 2
Bourns x 2
TDK Logo x 14
Pads x 2
TDK_Logo x 2
AVX_Logo x 3
notch
Panasonic
lead2
xx
cap
Murata Logo 3
Cap_KEMET_C0603C272M5JACTU_eec x 6

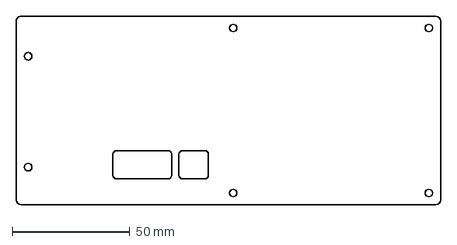
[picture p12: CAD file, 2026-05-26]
Hardware/top_panel.dxf
180.0 x 80.0 mm

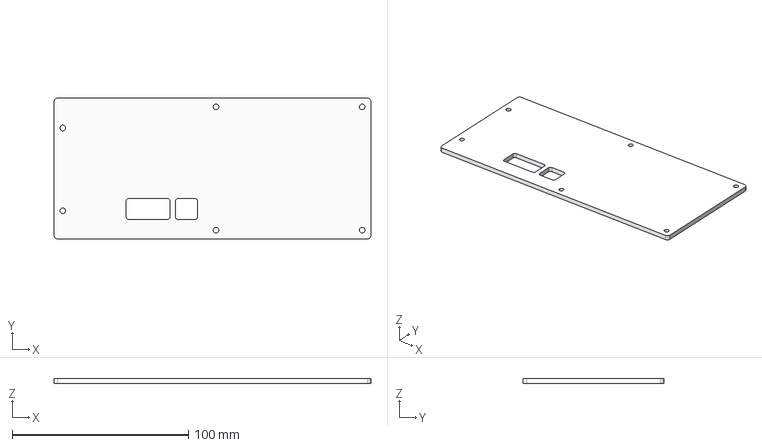
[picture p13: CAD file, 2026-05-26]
Hardware/top_panel_converted.step
180.0 x 80.0 x 3.00 mm

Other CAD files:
Hardware/Top Overlay.DXF
Hardware/Embedded Controller.step
Hardware/Top Overlay.DWG
Hardware/top_panel_converted.dxf

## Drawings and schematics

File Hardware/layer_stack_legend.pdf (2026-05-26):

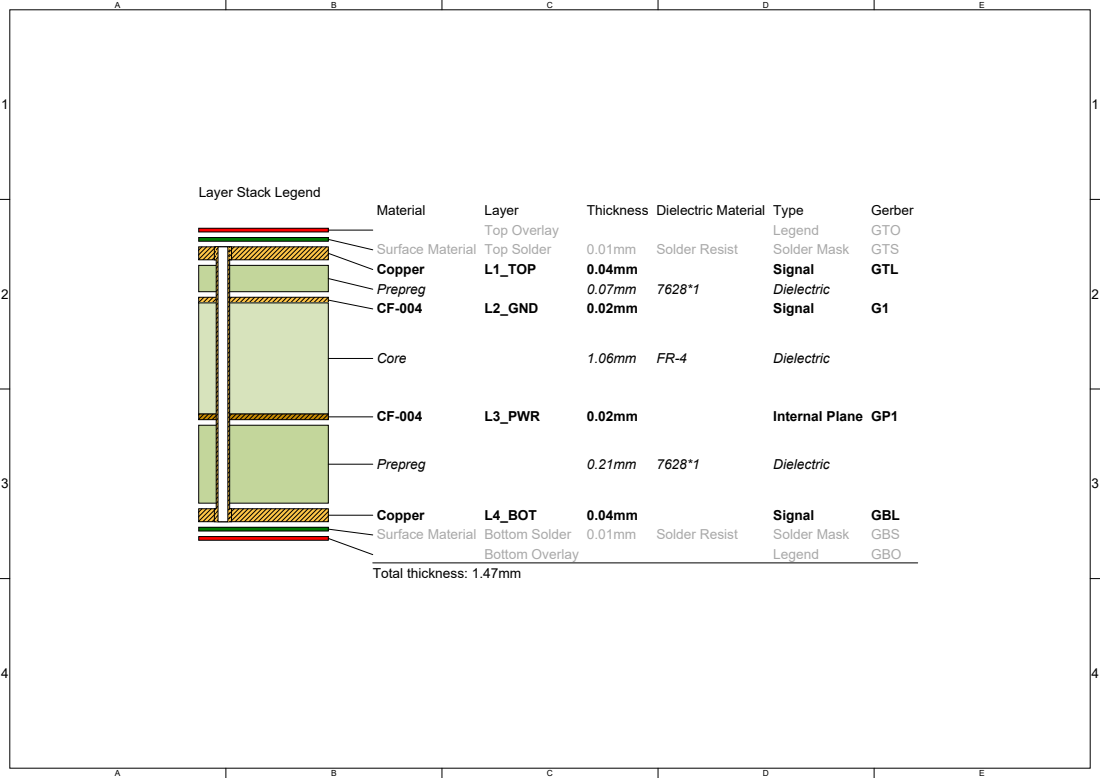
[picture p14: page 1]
Material; Layer; Thickness Dielectric Material Type; Gerber; Top Overlay; Legend; GTO; Surface Material Top Solder; Solder Resist; Solder Mask; GTS; Copper; L1_TOP; Signal; GTL; Prepreg; Dielectric; L2_GND; Core; L3_PWR; Internal Plane GP1; L4_BOT; GBL; Surface Material Bottom Solder 0.01mm; GBS; Bottom Overlay; GBO; Total thickness: 1.47mm

Layer Stack Legend

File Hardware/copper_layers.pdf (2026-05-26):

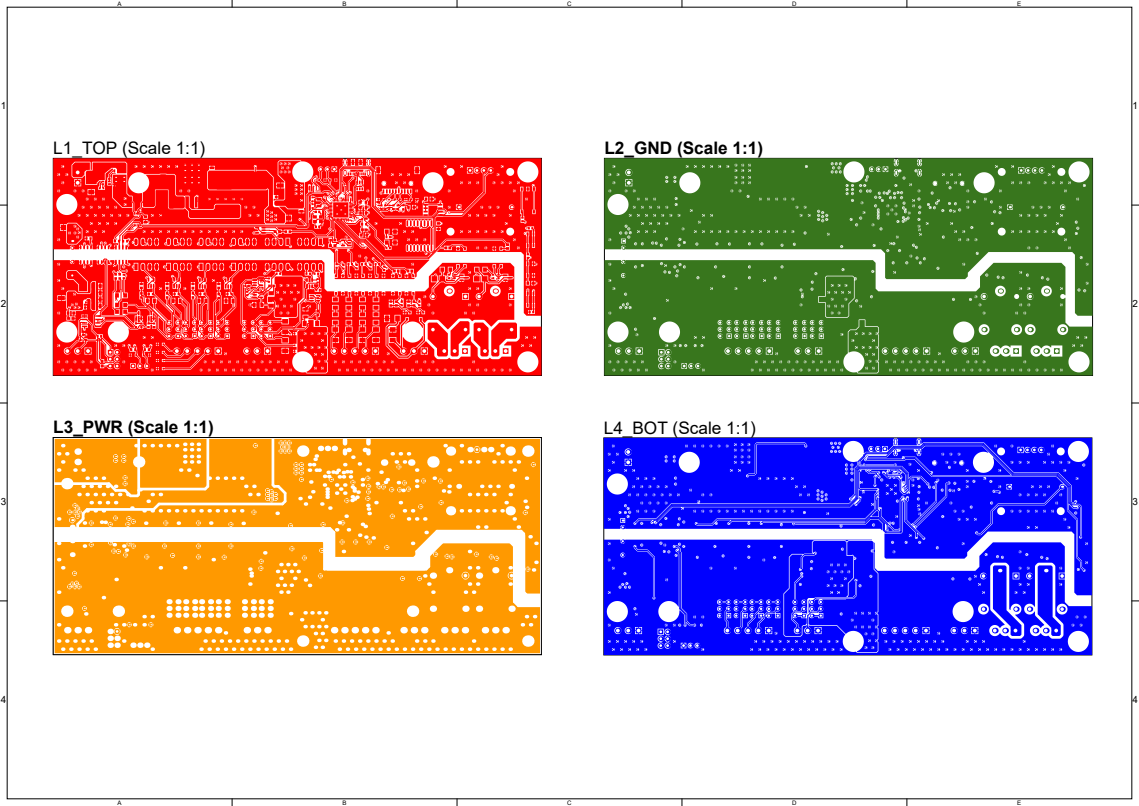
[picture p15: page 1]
L1_TOP (Scale 1:1); L2_GND (Scale 1:1); L3_PWR (Scale 1:1); L4_BOT (Scale 1:1)

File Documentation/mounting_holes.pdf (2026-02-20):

A

B

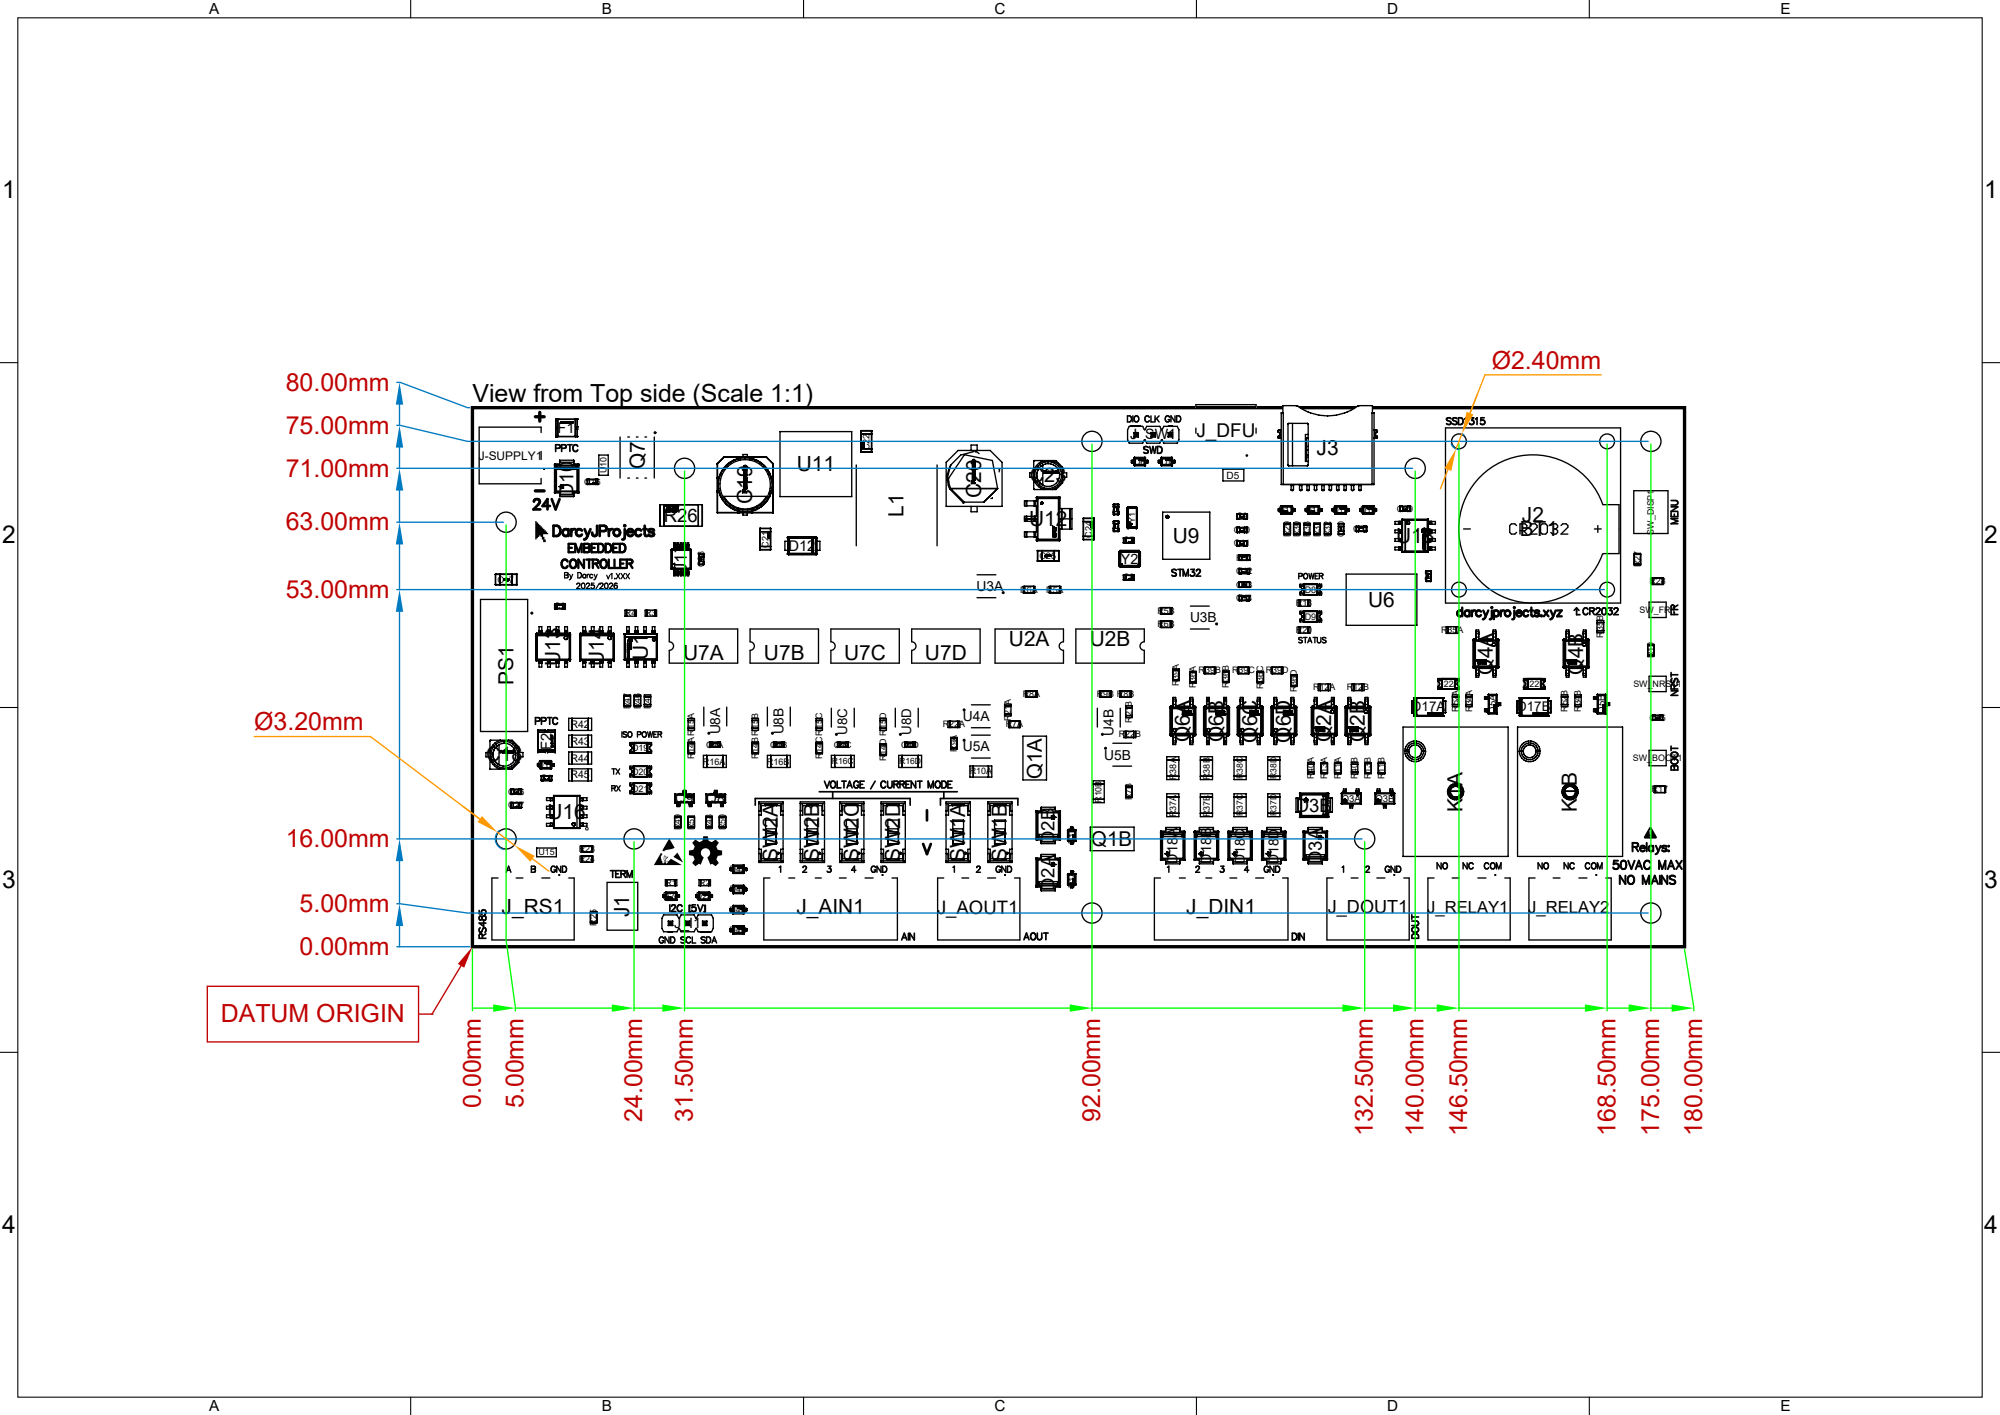
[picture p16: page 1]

View from Top side (Scale 1:1)

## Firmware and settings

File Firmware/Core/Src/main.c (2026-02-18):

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
/* Includes ------------------------------------------------------------------*/
#include "main.h"
#include "app_fatfs.h"
#include "usb_device.h"

/* USER CODE BEGIN Includes */
#include <stdio.h>
#include "rtc/rtc_ds3231.h"
#include "automation/automation.h"
#include "rs485/rs485.h"
#include "i2c/display.h"
#include "i2c/i2c.h"
#include "i2c/ina226.h"
#include "i2c/bmp280.h"
#include "sd/sd.h"
#include "io/io_modbus_slaves.h"
#include "io/io_emergency.h"
#include "i2c/eeprom_utils.h"
#include "splash_screens/splash_boot.h"
//#include "sensors/dht11.h"
/* USER CODE END Includes */

ADC_HandleTypeDef hadc1;

DAC_HandleTypeDef hdac1;

I2C_HandleTypeDef hi2c1;

SPI_HandleTypeDef hspi1;

UART_HandleTypeDef huart1;
DMA_HandleTypeDef hdma_usart1_rx;
DMA_HandleTypeDef hdma_usart1_tx;

void SystemClock_Config(void);
static void MX_GPIO_Init(void);
static void MX_DMA_Init(void);
static void MX_I2C1_Init(void);
static void MX_USART1_UART_Init(void);
static void MX_ADC1_Init(void);
static void MX_DAC1_Init(void);
static void MX_SPI1_Init(void);
/* USER CODE BEGIN PFP */

void SPI_ReInit(void) {
	MX_SPI1_Init();
}

/* USER CODE END PFP */

/**
  * @brief  The application entry point.
  * @retval int
  */
int main(void)
{

  /* MCU Configuration--------------------------------------------------------*/

  /* Reset of all peripherals, Initializes the Flash interface and the Systick. */
  HAL_Init();

  /* USER CODE BEGIN Init */

  // Add Channels
// COILS: Digital R/W: for this controller, all digital outputs
// DISCRETE INPUTS: Digital R: for this controller, all digital inputs
// HOLDING REGISTERS: Analogue R/W: for this controller, all analogue outputs
// INPUT REGISTERS: Analogue R: for this controller, all analogue inputs
  //io_coil_add_channel(GPIOC, GPIO_PIN_6);


  /* USER CODE END Init */

  /* Configure the system clock */
  SystemClock_Config();

  /* Initialize all configured peripherals */
  MX_GPIO_Init();
  MX_DMA_Init();
  MX_I2C1_Init();
  MX_USART1_UART_Init();
  MX_ADC1_Init();
  MX_DAC1_Init();
  MX_USB_Device_Init();
  MX_SPI1_Init();
  if (MX_FATFS_Init() != APP_OK) {
    Error_Handler();
  }
  /* USER CODE BEGIN 2 */
  // SETUP ---------------------------------------------------------------------------------------//
    // Splash Screen
	display_Setup();
	// Display after checking for factory reset

	// Config
	#define DEBOUNCE_DELAY 50 // milliseconds
	#define FACTORY_RESET_HOLD_TIME 5000 // milliseconds
	#define FACTORY_RESET_CHECK_INTERVAL 50 // milliseconds

	// Initialise I2C in case of factory reset
	I2C_Setup(&hi2c1);

	// Initialise SD if installed
	//HAL_Delay(2000);
	SD_Detect();
	SD_Log("System booting");


	// Check for Factory Reset
	GPIO_PinState factoryResetBtn = HAL_GPIO_ReadPin(GPIOB, BTN2_Pin);
	if (factoryResetBtn == GPIO_PIN_SET) {
		uint32_t heldTime = 0;

		SD_Log("Factory reset initiated by user");
		display_FactoryResetPage(0); // main

		while (1) {
			if (HAL_GPIO_ReadPin(GPIOB, BTN2_Pin) == GPIO_PIN_SET) {
				HAL_Delay(FACTORY_RESET_CHECK_INTERVAL);
				heldTime += FACTORY_RESET_CHECK_INTERVAL;

				if (heldTime >= FACTORY_RESET_HOLD_TIME) {
					// Button held for x ms, perform factory reset, and then continue as usual with boot
					if(!automation_factory_reset()) {
						// Reset Failed, display fail screen
						display_FactoryResetPage(2); // failure
						SD_Log("Factory reset failed");
						HAL_Delay(4000);

						// Continue with boot...
						break;
					} else {
						// Display success screen
						display_FactoryResetPage(1); // successful
						SD_Log("Factory reset successful");
						HAL_Delay(4000);

						// Continue with boot
						break;
					}
				}
			} else {
				display_FactoryResetPage(3); // cancelled
				SD_Log("Factory reset aborted by user");
				HAL_Delay(4000);
				// Continue with boot
				break;
			}

		}
	}

	splash_screen_boot_play(GPIOC, BTN1_Pin);

  	// Communication
    modbus_Setup(0x01); // Set modbus slave address
  	RS485_Setup(GPIOA, RS485_DIR_Pin); // changed from PA4 to PA8 to not interfere with DAC1 [RS485_Setup must be called AFTER modbus_setup]

  	// Initialise Devices
  	INA226_Init(&hi2c1);

  	// Setup Coils [HARDWARE]
  	gpio_config coil_0 = {GPIOC, DOUT1_Pin};
	gpio_config coil_1 = {GPIOB, DOUT2_Pin};
	gpio_config coil_2 = {GPIOB, DOUT3_Pin};
	gpio_config coil_3 = {GPIOB, DOUT4_Pin};
  	io_coil_add_channel(hardware_coil_write_func, &coil_0);
  	io_coil_add_channel(hardware_coil_write_func, &coil_1);
  	io_coil_add_channel(hardware_coil_write_func, &coil_2);
  	io_coil_add_channel(hardware_coil_write_func, &coil_3);

  	// Setup Discrete Inputs [HARDWARE]
  	gpio_config discrete_in_0 = {GPIOA, GPIO_PIN_2}; // PA2
  	gpio_config discrete_in_1 = {GPIOA, GPIO_PIN_3}; // PA3
  	gpio_config discrete_in_2 = {GPIOB, GPIO_PIN_13}; // PB13
  	gpio_config discrete_in_3 = {GPIOB, GPIO_PIN_14}; // PB14
  	io_discrete_in_add_channel(hardware_discrete_in_read_func, &discrete_in_0);
  	io_discrete_in_add_channel(hardware_discrete_in_read_func, &discrete_in_1);
  	io_discrete_in_add_channel(hardware_discrete_in_read_func, &discrete_in_2);
  	io_discrete_in_add_channel(hardware_discrete_in_read_func, &discrete_in_3);

  	// Setup Holding Registers [HARDWARE]
  	io_holding_reg_add_channel(dac_write_func, DAC_CHANNEL_1, IO_HOLDING_REG_VOLTAGE);
  	io_holding_reg_add_channel(dac_write_func, DAC_CHANNEL_2, IO_HOLDING_REG_VOLTAGE);


  	// Setup Input register
  	io_input_reg_add_channel(adc_read_func, ADC_CHANNEL_1, IO_INPUT_REG_VOLTAGE);
  	io_input_reg_add_channel(adc_read_func, ADC_CHANNEL_2, IO_INPUT_REG_VOLTAGE);
  	io_input_reg_add_channel(adc_read_func, ADC_CHANNEL_11, IO_INPUT_REG_VOLTAGE);
  	io_input_reg_add_channel(adc_read_func, ADC_CHANNEL_14, IO_INPUT_REG_VOLTAGE);

  	// Hardcoded Status input registers (do not remove)
  	io_input_reg_add_channel(INA226_ReadBusVoltageRaw, &hi2c1, IO_INPUT_REG_VOLTAGE);
  	io_input_reg_add_channel(INA226_ReadCurrentRaw, &hi2c1, IO_INPUT_REG_VOLTAGE);

  	// Initialise Automation
  	// This MUST be done AFTER the physical channels have been added ^^ or else the stored analogue modes (voltage/current) cannot be set
  	automation_Init();

  	// TODO: DEMO ONLY - BMP280
	//BMP280_Init();
	//io_input_reg_add_channel(BMP280_Read_Temp_Func, NULL, IO_INPUT_REG_I2C);

  	// TODO: DEMO ONLY - MODBUS SLAVE
  	/*
  	// Setup the SHT30 as a Modbus slave
  	io_modbus_slave_add_channel(0x1E, MODBUS_REGISTER_INPUT, 0); // SHT30 slave, humidity
  	io_modbus_slave_add_channel(0x1E, MODBUS_REGISTER_INPUT, 1); // SHT30 slave, temperature
  	// Add these input register (buffers) as input registers
  	io_input_reg_add_channel(io_modbus_slave_read, 0); // modbus slave channel 0 = humidity
  	io_input_reg_add_channel(io_modbus_slave_read, 1); // modbus slave channel 1 = temperature
  	// Note, these values need to be / 10 to get actual value.
	*/

  	// Flash on-board LED
  	HAL_GPIO_WritePin(GPIOC, LED_Pin, GPIO_PIN_SET);
  	HAL_Delay(60);
  	HAL_GPIO_WritePin(GPIOC, LED_Pin, GPIO_PIN_RESET);
  	HAL_Delay(60);
  	HAL_GPIO_WritePin(GPIOC, LED_Pin, GPIO_PIN_SET);
  	HAL_Delay(60);
	HAL_GPIO_WritePin(GPIOC, LED_Pin, GPIO_PIN_RESET);

	HAL_Delay(2500);

	SD_Log("System boot complete");

	// TEMP: ->> needs to be in a timer to update every few seconds for eg TODO
	display_StatusPage();

  // ---------------------------------------------------------------------------------------------//
  /* USER CODE END 2 */

  /* Infinite loop */
  /* USER CODE BEGIN WHILE */

	uint8_t btn1status = 0;
	uint32_t lastButtonPress = 0;

	uint32_t loopCounter = 0;
	uint32_t lastTimeTick100ms = HAL_GetTick();
	uint32_t lastTimeTick1000ms = HAL_GetTick();
	uint32_t sdSecondCount = 0;
	bool displayingSDStatus = false;

	bool boot0_pressed = false;

  while (1)
  {
	  loopCounter++;

	  /* CHECK FOR EMERGENCY STOP BEGIN*/
	  if (emergencyStop_check()) {
		  break; // Do not continue with main loop.
	  }
	  /* CHECK FOR EMERGENCY STOP END*/

	  /* RS485 Circular Frame Handling BEGIN*/
	  RS485_ProcessPendingFrames();
	  RS485_TransmitPendingFrames();
	  /* RS485 Circular Frame Handling END*/

	  /* MODBUS SLAVE POLLING (US AS MASTER) BEGIN*/
	  io_modbus_slave_poll_all();
	  modbus_master_poll_timeout();
	  /* MODBUS SLAVE POLLING (US AS MASTER) END*/

	  /* AUTOMATION BEGIN*/
	  automation_Tick();
	  /* AUTOMATION END*/


	  /* CHECK INPUTS BEGIN*/
	  // Check display button
	  GPIO_PinState btn1 = HAL_GPIO_ReadPin(GPIOC, BTN1_Pin);
	  if (btn1 == GPIO_PIN_SET) {
		  if (btn1status == 0 && (HAL_GetTick() - lastButtonPress) > DEBOUNCE_DELAY) {
			  display_BtnPress();
			  lastButtonPress = HAL_GetTick();
			  btn1status = 1;
		  }
	  } else if (btn1 == GPIO_PIN_RESET) {
		  btn1status = 0;
	  }
	  /* CHECK INPUTS END*/


	  /* SCHEDULE BEGIN*/
	  // Every 100ms
	  if ((HAL_GetTick() - lastTimeTick100ms) >= 100 || (HAL_GetTick() < lastTimeTick100ms)) { // wraparound-safe comparison
		  lastTimeTick100ms = HAL_GetTick();

		  // Check if BOOT0 button pressed
		  GPIO_PinState boot0 = HAL_GPIO_ReadPin(GPIOB, BOOT0_Pin);
		  if (boot0 == GPIO_PIN_SET) {
			  display_dfu();
			  boot0_pressed = true;
		  } else if (boot0_pressed) {
			  display_StatusPage();
			  boot0_pressed = false;
		  }
	  }


	  // Every second
	  if ((HAL_GetTick() - lastTimeTick1000ms) >= 1000 || (HAL_GetTick() < lastTimeTick1000ms)) { // wraparound-safe comparison
		  lastTimeTick1000ms = HAL_GetTick();

		  loopCounter = 0;

		  if (displayingSDStatus) {
			  //usb_serial_println("displayingSDstatus");
			  if (sdSecondCount >= 2) { // show for 2s
				  displayingSDStatus = false;
				  sdSecondCount = 0;

				  // Update display if boot0 is not pressed
				  if (boot0_pressed == false) {
					  display_StatusPage();
				  }
			  } else {
				  sdSecondCount++;
			  }
		  } else {
			  //usb_serial_println("sd status triggered 1");
			  // Check for SD card insertion/removal
			  SD_Status sd_status = SD_Detect(); // Will automatically mount/unmount
			  if (sd_status == SD_INSERTED_MOUNT_FAILURE || sd_status == SD_INSERTED_MOUNT_SUCCESS || sd_status == SD_REMOVED) {
				  //usb_serial_println("sd status triggered 2");
				  display_sd_status(sd_status);
				  displayingSDStatus = true;
			  } else {
				  // Update display if boot0 is not pressed
				  if (boot0_pressed == false) {
					  display_StatusPage();
				  }
			  }
		  }
	  }

	  // Every 10 seconds since pressing display button, go to main page
	  if ((HAL_GetTick() - lastButtonPress) >= 10000|| (HAL_GetTick() < lastButtonPress)) { // wraparound-safe comparison
		  if (!displayingSDStatus) {
			  display_setPage(0);
		  }
	  }

	  /* SCHEDULE END*/

    /* USER CODE END WHILE */

    /* USER CODE BEGIN 3 */

	  /*HAL_GPIO_WritePin(GPIOC, LED_Pin, GPIO_PIN_SET);
	  HAL_Delay(500);
	  HAL_GPIO_WritePin(GPIOC, LED_Pin, GPIO_PIN_RESET);
	  HAL_Delay(500);
		*/

	  // Get current time
	  /*RTC_Time currentTime;
	  char timeStr[16];
	  if (DS3231_ReadTime(&currentTime) == HAL_OK) {
		  snprintf(timeStr, sizeof(timeStr), "%02d:%02d:%02d", currentTime.hours, currentTime.minutes, currentTime.seconds);
	  } else {
		  snprintf(timeStr, sizeof(timeStr), "Error!");
	  }

	  // Clear display
	  ssd1306_Fill(Black);

	  // Set cursor position
	  ssd1306_SetCursor(10, 25);  // adjust x, y as needed

	  // Write string to buffer
	  ssd1306_WriteString(timeStr, Font_11x18, White);

	  // Update display with buffer content
	  ssd1306_UpdateScreen();

	  HAL_Delay(200);*/

  }
  /* USER CODE END 3 */
}

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


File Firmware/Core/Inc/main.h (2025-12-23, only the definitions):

#define VERSION "1.162"
#define BTN1_Pin GPIO_PIN_13
#define BTN1_GPIO_Port GPIOC
#define AIN1_Pin GPIO_PIN_0
#define AIN1_GPIO_Port GPIOA
#define AIN2_Pin GPIO_PIN_1
#define AIN2_GPIO_Port GPIOA
#define DIN1_Pin GPIO_PIN_2
#define DIN1_GPIO_Port GPIOA
#define DIN2_Pin GPIO_PIN_3
#define DIN2_GPIO_Port GPIOA
#define AOUT1_Pin GPIO_PIN_4
#define AOUT1_GPIO_Port GPIOA
#define AOUT2_Pin GPIO_PIN_5
#define AOUT2_GPIO_Port GPIOA
#define DOUT1_Pin GPIO_PIN_4
#define DOUT1_GPIO_Port GPIOC
#define DOUT2_Pin GPIO_PIN_0
#define DOUT2_GPIO_Port GPIOB
#define DOUT3_Pin GPIO_PIN_1
#define DOUT3_GPIO_Port GPIOB
#define DOUT4_Pin GPIO_PIN_2
#define DOUT4_GPIO_Port GPIOB
#define AIN4_Pin GPIO_PIN_11
#define AIN4_GPIO_Port GPIOB
#define AIN3_Pin GPIO_PIN_12
#define AIN3_GPIO_Port GPIOB
#define DIN3_Pin GPIO_PIN_13
#define DIN3_GPIO_Port GPIOB
#define DIN4_Pin GPIO_PIN_14
#define DIN4_GPIO_Port GPIOB
#define LED_Pin GPIO_PIN_6
#define LED_GPIO_Port GPIOC
#define RS485_DIR_Pin GPIO_PIN_8
#define RS485_DIR_GPIO_Port GPIOA
#define RS485_TX_Pin GPIO_PIN_9
#define RS485_TX_GPIO_Port GPIOA
#define RS485_RX_Pin GPIO_PIN_10
#define RS485_RX_GPIO_Port GPIOA
#define SD_CARD_Pin GPIO_PIN_10
#define SD_CARD_GPIO_Port GPIOC
#define SD_CS_Pin GPIO_PIN_11
#define SD_CS_GPIO_Port GPIOC
#define BOOT0_Pin GPIO_PIN_8
#define BOOT0_GPIO_Port GPIOB
#define BTN2_Pin GPIO_PIN_9
#define BTN2_GPIO_Port GPIOB
#define SD_CS_Pin GPIO_PIN_11
#define SD_CS_GPIO_Port GPIOC
#define SD_SPI_HANDLE hspi1

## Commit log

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2025-04-19 Implement digital IO module
    - Added a new `io` to manage GPIO channels (inputs and outputs) (digital only)
    - Introduced `io_add_channel()` to dynamically add GPIO channels
    - Added `io_read()` to read the state of input channels
    - Added `io_write()` to set the state of output channels
    - Defined a fixed limit (`MAX_IO_CHANNELS`) for the number of IO channels
    - Added basic error handling for invalid channels or operations
    [main.c]
2025-04-20 Implement custom DHT11 sensor driver
    - Implemented custom DHT11 sensor driver
    - Commented code for all added modules.
    - Recreated main.c isolated DHT11 testing.
    - Updated io_analogue to use generic handles (void*) to avoid ADC/DAC build errors when HAL is not enabled
    - Rename IO direction macros in io_digital.h to IO_DIGITAL_INPUT and IO_DIGITAL_OUTPUT for clarity
    [dht11.c, io_analogue.c, io_digital.c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]
2025-04-21 Implement RS485 transmit
    - Implemented a basic RS485 module, capable of transmitting data over RS485 via USART (rs485/rs485.h,rs485.c)
    - Fixed errors relating to an incomplete change over from IO_OUTPUT/INPUT to IO_DIGITAL_OUTPUT/INPUT macros in io_digital module
    RS485 tested with STM32 -> TXS0108E -> MAX485 ==RS485== MAX485 -> ATMega328p printing received bytes over serial. Transmit confirmed to be working.
    [io_digital.c, main.c, main.h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]
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2025-04-22 Migrate RS485 Transmit to DMA
    - Migrated the RS485 transmit to use DMA.
    - Previous (now reverted github commit) attempt broke things.
    - TODO: Add queue for transmits in case a transmit is called while one is still being transmitted.
    [main.c, main.h, rs485.c]
2025-04-22 RS485 Transmit - TC Interrupt
    - RS485 transmission now uses the UART transmission complete (TC) interrupt to signal when the transmission has completed. Before, was just a short hard coded delay.
    [main.c, rs485.c]
2025-04-23 Modbus RTU over RS485 Demo
    - Very limited implementation of Modbus over RS485.
    - MODBUS_FUNC_READ_HOLDING_REGISTERS tested, WRITE_SINGLE_REGISTER not tested yet.
    - No CRC checks implemented yet
    - Very limited so far!
    - Response confirmed over RS485 after receiving a test modbus frame, however, I want to swap to using a RS485-USB adapter rather than an Arduino so I can test it further and more reliably
    [main.c, modbus.c, rs485.c]
2025-04-23 RS485 Transmit - TC Interrupt Handling Fix
    - Fixed handling of post transmit code with TC interrupt, moving post transmit code out of HAL_UART_TxCpltCallback into USART2_IRQHandler (calling RS485_TCCallback(void).
    - Fixes possible (but not observed) issue where if TC flag is not set in time, post transmission code may not be run.
    [rs485.c]
2025-04-23 Modbus RTU - Implement CRC16 check
    - Implemented static function for modbus module: modbus_crc16
    - Provide frame and len and will return calculated crc16. Source of function in modbus.c
    - Fixed missing breaks in the switch statement in modbus.c
    [modbus.c]
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2025-05-01 Modbus: CRC, Read Holding Registers (0x03) fixes
    - Calculated CRC16 fix - was including the original CRC16 in the calculation which is wrong so "len" is now "len - 2" (minus the 2 CRC bytes)
    - Fixed Read Holding Registers (0x03) response byte count - was returning number of registers (16 bits / 2 bytes), not number of actual bytes (fix: regCount * 2 rather than just regCount)
    [main.c, modbus.c]
2025-05-01 MODBUS: Read Holding Registers fix
    - Read Holding Registers (0x03) was skipping the first byte of the register value.
    - Read Holding Registers (0x03) and Write Single Register (0x06) CONFIRMED working with RS485 to USB adapter and QModMaster
    [modbus.c]
2025-05-01 MODBUS: Added Write Multiple Registers (0x10), Bug Fixes
    - Added Write Multiple Registers function (0x10) and confirmed working
    - Fixed logical error with comparison for testing out of bounds registers for Read Holding Registers
    - Fixed send_exception to include crc16 (forgot to include earlier)
    - Fixed send_exception echoed function -> needs to OR with 0x80 to indicate that its an exception
    - Fixed received_crc in modbus_handle_frame to handle frames of any valid length (not just 8 bytes).
    [modbus.c]
2025-05-01 IO, MODBUS: Added io_coils.h, MODBUS coil functions, bug fixes
    - Added a new module specifically for coils - digital inputs/outputs that modbus has access to.
    - io_digital will be reserved for internal digital I/O that is not to be configured over modbus e.g., hardwired buttons for OLED display for example on the PCB
    - Fixed IO_Digital_Direction enum naming - change must have been reverted, but reinstated again.
    - Added MODBUS functions Read Coils (0x01), Write Single Coil (0x05) and Write Multiple Coils (0x0F).
    [io_coils.c, io_digital.c, main.c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]
2025-05-01 IO, MODBUS: Corrected io_coil implementation, coil functions
    - Coils are to be all digital I/O that can be read & written to. This is consistent with digital out for this controller, so only digital out are coils. Removed direction from coil module.
    - Updated modbus functions relating to coils to reflect this: 0x01, 0x05, 0x0F
    - Fixed channel out of bounds checking for coils.
    [io_coils.c, main.c, modbus.c]
2025-05-02 IO, MODBUS: Added io_discrete_in, io_holding_reg, MODBUS functions updated, Implemented discrete inputs
    - Created new IO module for discrete inputs (which are only digital inputs on this controller). Externally accessible by modbus, whereas io_digital is internal only.
    - Created new IO module io_holding_reg for holding registers. Only performs DAC, reads are from storing previous written value. Scales 16 bit modbus values down to 12 bit values for the DAC.
    - Bug fixes in io_analogue for DAC handle.
    - Implemented MODBUS function read discrete inputs (0x02).
    - Bug fixes for exception checking for modbus functions.
    - Changed SD_CS pin to PA13 as it was using a pinout for DAC1.
    [io_analogue.c, io_coils.c, io_discrete_in.c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]
2025-05-02 MODBUS: Fix Write Multiple Registers 0x10
    - Fixed modbus function write multiple registers (0x10). Forgot to update write value to register line.
    [modbus.c]
2025-05-02 IO, MODBUS: Added io_input_reg module, MODBUS functions expanded, Fixes
    - Incorporated the final MODBUS i/o addition: input_registers which are equivalent to analogue inputs on this controller.
    - Added modbus function Read Input Registers (0x04)
    - Fixed issue with ADC handle for io_analogue writes.
    - Set pins for ADC (analogue ins: input registers) and DAC (analogue outs: holding registers)
    [io_analogue.c, io_holding_reg.c, io_input_reg.c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]
2025-06-08 MIGRATE TO STM32G431CBU6, I2C support to input registers
    Created new project for the STM32G431CBU6 -> 1/2 the price & was having issues with the G474CEU6 board i have.
    Migrated all modules over to this new project.
    + Added I2C support to input registers -> channels now are provided with a read_function and context (parameter). For physical ADC inputs, there is a read_func provided. For I2C inputs, this is obviously device specific and needs to be implemented (needs to take a void* context parameter, and return type must be uint16_t).
    + Bug fixes.
    + Added read function for DS3231 temperature (has in built temp sensor) for testing I2C input register over modbus.
    [PLC Project.ioc, bmp280.c, dht11.c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]
2025-06-09 RS485: RX/TX Circular Buffer
    Added a circular buffer for RX and TX.
    RS485.c will automatically buffer received frames, and frames to be transmitted, but to actually trigger the processing and transmission of the buffered frames, the following functions must be called from a loop (i.e., main while(1) loop):
    RS485_ProcessPendingFrames(); // sends frames to modbus to process
    RS485_TransmitPendingFrames(); // self explanatory
    Work required to further validate TCCallback interrupt <-- acting strangely.
    NTS:
    rs485_tx_frame_tail = (rs485_tx_frame_tail + 1) % RS485_FRAME_QUEUE_LEN;
    line 163 in rs485.c will NOT work when placed in TCCallback instead. Strange issue.
    [main.c, rs485.c]
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2025-06-10 Display Update, Increased I2C support
    + Added page support to the display, where BTN1 changes through the pages.
    + Added a coils page to display states of all four physical coils.
    + Extended io_discrete_in to support I2C devices. See main.c setup for how to add the physical channels.
    + Added INA226 I2C library - untested as of yet -> think my module is damaged.
    [PLC Project.ioc, display.c, i2c.c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]
2025-06-10 INA226 Fixed, Display Stats
    + INA226 library completed to provide raw and float values for Bus Voltage, Current, and Power.
    + Utilises i2c.h/c
    + Bug fixes with display scheduling and functions
    + Wraparound safe scheduler code bug fixes
    + Display now displays INA226 voltage and current stats.
    [display.c, ina226.c, main.c]
2025-06-10 Display, Input Reg Fixes
    + Added extra pages on the display for viewing all hardware modbus I/O
    + Added ssd1306_icons.h/c -> offers 6x8 icons. 11x18 not working yet.
    + Fixed io_input_reg.c -> adc_read_func now actually reads the correct channel (forgot channel selection before).
    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
    [PLC Project.ioc, display.c, ina226.c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]
2025-06-11 Altium Project Initial Commit
    Altium Project including unfinished circuit designs for:
    + Analogue Out Isolator
    + Digital Out Isolator
    + I2C Isolator
    + DS3231 RTC
    [AOut_Isolator.SchDoc, DOut_Isolator.SchDoc, I2C_Isolator.SchDoc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]
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2025-06-13 Web Panel Status Functionality
    FIRMWARE:
    + Added hard coded status input registers for bus voltage (supply) and current draw (input register addresses 4 and 5 respectively).
    WEB-PANEL
    + Extends status page over modbus to the web panel.
    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
    [main.c]
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2025-06-14 Automation Rules over MODBUS
    + Added a custom "vendor" function (0x65) 'addRule' which adds an automation rule to the controller.
    -> doesn't store to EEPROM yet, is volatile currently.
    + Added modbus_vendor module to support extra functions over modbus.
    Web-Panel backend server is still having issues with receiving the response from custom functions, so this has not been committed yet as I'm going to rewrite later.
    [main.c, modbus.c, rs485.c]
2025-06-15 Web Panel: Custom MODBUS Library, Add rules over MODBUS web panel
    + Difficult to add RX for custom functions with modbus-serial, so I've written a custom modbus library that supports custom functions, albeit with probably worse error handling, but I will try to improve it over time.
    + Added rules manager to the web panel, however, the front end has not been linked to the back end yet.
    + Switched to navigation tabs for the web panel tools.
2025-06-16 RS485: UARTErrorCallback
    Added HAL_UART_ErrorCallback to restart UART ReceiveToIdle DMA if it fails.
    [rs485.c]
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2025-06-17 Virtual Registers: virtual module, io bug fixes
    + Added virtual.c/h module for virtual registers which are IO that have no external output. Basically variables, within coils or holding registers (no discrete in or input reg yet).
    + Bug fixes
    [io_coils.c, io_holding_reg.c, io_input_reg.c]
2025-06-18 Web Panel: Port disconnect event
    + Added a port disconnect event to fix bugs occurring due to port disconnection while connected
    + Added a refresh button to the port ComboBox
    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
2025-06-21 Virtual Registers: Overhaul
    Separated virtual register storage from physical/i2c io coils and holding registers. Now stored in their own array to separate addresses.
    Virtual registers are no longer real coils or real holding registers, and can only be updated via vendor functions:
    #define MODBUS_VENDOR_FUNC_ADD_VIRTUAL_REG 0x75
    #define MODBUS_VENDOR_FUNC_READ_VIRTUAL_REG 0x76
    #define MODBUS_VENDOR_FUNC_WRITE_VIRTUAL_REG 0x77
    #define MODBUS_VENDOR_FUNC_GET_VIRTUAL_REG_COUNT 0x78
    - Need to still allow rules to interact with virtual registers. Not implemented yet.
    [display.c]
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2025-06-28 Altium: AIN Isolator Confirmed
    + AIN Isolator tested on a breadboard and confirmed.
    + Will need to add calibration to firmware.
    + Suggest hardware oversampling for ADC as lose circa 0.8bits of resolution due to reduced input voltage to STM32 from nsi1200
    + Supports current input (10R shunt resistor) and voltage input
    --> Need to buy a DPDT slide switch and correct the footprint.
    [AIn_Isolator.SchDoc]
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2025-06-28 Altium: AOUT V and I output
    + Added a 4-20mA output circuit for the analogue out circuit
    + Finalised design for aout.
    --> need to change DPDT footprint to correct one once switch is sourced.
    Note, designed for 24V 4-20mA current output, but 5V voltage output. The AOUT pin is a sourcing 5V pin in voltage mode, and a sinking 24V pin (high side) in current mode, where AGND must be connected to the low side of the load.
    [AIn_Isolator.SchDoc, AOut_Isolator.SchDoc, STM32_MCU.SchDoc]
2025-06-30 Factory Reset: BTN2
    + Added factory reset on boot feature when holding down BTN2
    + Clears EEPROM, nothing else.
    + Added display messages for this process.
    -> Hold down BTN2 for 5 seconds when booting (doesn't wait for you to press it so hold down BTN2, then press NRST, and keep holding BTN2 until reset).
    [PLC Project.ioc, display.c, main.c]
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2025-06-30 Factory Reset: Fix BTN port
    + Correct BTN2 port to GPIOB from GPIOA.
    [main.c]
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2025-07-01 SD Card Logging
    + Added an SD module to facilitate SD card logging
    + Changed SD card CS pin as to not interfere with SWD
    + Configured SPI1, FatFS, Kiwih's additions, etc.
    See this article as this was my main support for SD card integration:
    https://01001000.xyz/2020-08-09-Tutorial-STM32CubeIDE-SD-card/
    [PLC Project.ioc, main.c, main.h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]
2025-07-01 Altium: Update SD_CS pin mapping
    Changed as to not interfere with SWD.
    [STM32_MCU.SchDoc]
2025-07-01 Altium: Remove redundant 24_ISO supply
    + Removed redundant 24_ISO supply as I have decided digital outputs will be sinking, not sourcing, and thus a 24V isolated source is no longer required (can use 5V_ISO for MOSFET gate).
    [Power_Supply.SchDoc]
2025-07-03 Altium: Digital IO Confirmation, LTV356 footprint correction
    + Confirmed functionality of DOUT, DIN, DOUT_RELAY
    + Corrected flyback diode orientation for the relay.
    + Corrected the LTV356 footprint
    [AIn_Isolator.SchDoc, AOut_Isolator.SchDoc, DIn_Isolator.SchDoc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]
2025-07-04 Altium: PCB Design Start, RS485
    + RS485 isolation circuit confirmed
    + Started arranging the PCB design
    --> Need to swap out RS485 jumper-pads with pins for easier configuration.
    [DOut_Relay.SchDoc, I2C_Display.SchDoc, I2C_Isolator.SchDoc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]
2025-07-12 Modbus Master Support
    + Added support for Modbus slaves as inputs and outputs (i.e., this controller acting as the master).
    + Modbus slave addresses can be added as i/o, which are polled every x ms, unlike normal i/o (hardware, i2c) that is polled only when read.
    + Requests are made to read the modbus slave by the poller. A buffer is stored to return the value when actually read.
    + For the modbus slave values to be read over modbus (with the controller acting as a slave), they must be added as a regular i/o channel with the modbus read function. (see demo in main.c)
    + RS485.c will swap between modbus_slave and modbus_master for frame processing depending on the slave id in the received frame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
    [display.c, main.c, modbus_slave.c]
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2025-07-12 Altium: Designators
    + Updated designator naming scheme for hierarchically created components
    + Updated PCB layout
    + Changed the solder bridges for enabling/disabling RS485 termination to pin headers to be jumpered.
    + Small fixes/additions
    [AIn_Isolator.SchDoc, AOut_Isolator.SchDoc, BTN2_FactoryReset.SchDoc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]
2025-07-13 Altium: 10uF cap footprint
    + Fixed footprints for the 10uF aluminium SMD capacitors.
    [Power_Supply.SchDoc]
2025-07-13 Altium: 10uF cap footprint
    (forgot to save Power_Supply.SchDoc)
    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
    [Power_Supply.SchDoc]
2025-07-13 Altium: Inductor footprint
    + Corrected the inductor footprint used on the buck converter
    [Power_Supply.SchDoc, STM32_MCU.SchDoc]
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2025-07-15 Altium: Fix stackup, polygons
    + Fixed stack-up -> now 2 layer PCB as intended.
    + added bottom power planes
    --> NEED TO FIX UNCONNECTED NETS DUE TO ISOLATED GND PLANES
    [BTN2_FactoryReset.SchDoc]
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2025-07-15 Altium: AIN Switch fix
    + Fixed wiring for AIN 2P2T switch for current/voltage mode selection.
    [AIn_Isolator.SchDoc]
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2025-07-17 Altium: Fixed pull-up for I2C field side
    + Pull up resistors for I2C field side were not connected to 3V3. Fixed - schematic and pcb.
    [I2C_Isolator.SchDoc, Power_Supply.SchDoc]
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2025-07-20 Holding Register Modes Fixed, Bug Fixes
    + Fixed the load from and save to EEPROM functions for the holding register mode.
    + Fixed final base address calculation at the end of the virtual load
    + Fixed the automation EEPROM load as it would not continue loading virtual and thus holding reg EEPROM if there was an automation rule count of 0.
    + Fixed redeclaration of crc16 functions throughout the firmware due to crc16 function being moved to modbus_util.h
    Note, automation_Init() must be called AFTER adding each physical channel in main.c/
    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
    [io_holding_reg.c, main.c]
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2025-07-22 Altium: Mounting holes moved
    + Moved the top right mounting hole as to reduce chance of interference with right DIN rail mount.
    + Moved all buttons and OLED as a result.
    --> Needs DRC
    [AIn_Isolator.SchDoc]
2025-07-22 Altium: Added pull down for DOUT
    + Added a high resistance pull down resistor between the gate and source of the AO3400A MOSFETS used for the sinking DOUT channels.
    + The 100K pull down with the 10K pull up results in a gate voltage of around 4.55V which is fine.
    + But, when power is lost, the gate will drain to GND through the 100K switching it off. -> better fail safe behaviour than just floating!
    + Updated schematics and PCB
    [DOut_Isolator.SchDoc]
2025-07-23 Emergency Stop
    + Added an emergency stop module that allows a discrete input to be used as an emergency stop trigger.
    + Once triggered, it is latched and the main loop will not continue. All coils and holding registers are also set to OFF/0. A reboot is required to exit.
    + Set the discrete input with emergencyStop_setInput(index, mode);
    where index is the channel index of the discrete input.
    where mode is EMERGENCY_STOP_NO or EMERGENCY_STOP_NC.
    + Added an emergency stop page to the display
    + Added a turn off all method to coils and holding registers.
    [display.c, io_coils.c, io_discrete_in.c]
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2025-07-23 Web Panel: Emergency Stop Config (Front End)
    + Added front end configuration of emergency stop button to the hardware configuration tab.
    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
2025-07-23 Fix Scheduler
    Fixed bug with scheduler causing display stats page to be called every 100ms, not every 1s.
    [main.c]
2025-07-24 Altium: Fixed I2C isolator capacitors
    + Rewired decoupling capacitors for ISO1540 I2C isolator. (wired wrong)
    [I2C_Isolator.SchDoc]
2025-07-24 Altium: Main PCB
    + Fixed I2C isolator
    + Moved CR2032 holder to beneath the OLED display as to not interfere with the DIN rail on the back of the board
    + Silkscreen changes
    + Removed polygon pours from inside keep out area around mounting holes
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2025-07-24 Altium: PCB DFM Fixes
    + Small fixes to traces to rectify minor DFM issues.
    [Main_Copper_Signal_Bot.gbr, Main_Copper_Signal_Top.gbr, Main_Legend_Bot.gbr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]
2025-07-25 OLED Burn In Protection, SD Fixes
    + Added OLED burn in protection (need to update interval to 30s or 60s -> current at 1s for testing)
    + Working on SD card detection fixes. Not finished.
    [display.c, main.c, main.h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]
2025-07-25 Uptime
    + Added Uptime to RTC status page
    + Set burn out interval to 30s
    + Disable heartbeat - i don't like the look of it
    [display.c]
2025-12-22 SD: Fixed reinsert reinit, EEPROM: Added eeprom_utils
    + Fixed SD card not remounting after being removed and reinserted.
    + Added EEPROM UTILS module for wiping and dumping the EEPROM. Only for development use.
    [main.c, sd.c]
2025-12-22 Display, SD: insertion, removal pages
    + Added a display page for when the SD card is inserted or removed, including when mounting succeeds or failed on insertion
    + Bug Fix: re-enabled card detection in sd.h
    [display.c, main.c, sd.c]
2025-12-23 Display: SD status, icons, skip splash
    + Added an icons.c file for bitmaps of icons (i.e., sd card)
    + Updated the sd card status display page formatting, and added SD card icon
    + Added skip splash functionality -> hold down the display button and it will skip the splash. Button press is checked before running the next screen.
    [display.c, main.c, splash_boot.c]
2026-01-06 Altium: Fix misrouted diode in buck converter
    + Diode was connected to OUT and FB -> should not be connected to FB. Fixed.
    [Power_Supply.SchDoc]
2026-01-21 Altium: LM2596s to 5.0 fixed output
    + Changed the power supply buck circuitry from using a LM2596s-adj to the fixed 5.0 model.
    + Hence removed voltage divider setting FB voltage, and connected directly to output rail instead.
    [Power_Supply.SchDoc]
2026-01-21 Altium: Buck Catch Diode 40V to 60V rating
    + Swapped catch diode for buck converter from SS34 (3A 40V) to SS36 (3A 60V) for higher voltage spike resilience.
    + Increased footprint size
    [Power_Supply.SchDoc]
2026-01-21 Altium: Catch Diode Footprint
    + Fixed catch diode footprint
    [Power_Supply.SchDoc]
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2026-01-23 Altium: AOUT Field Side
    + Changed current sense resistor to 100R, and swapped MMBT2222A to a BCP56 to better handle the power dissipation at 24V.
    + Changed base resistor to 470 ohms as incorrect value was previously used.
    + Circuitry prototyped, tested and validated on breadboard.
    [AOut_Isolator.SchDoc]
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2026-01-23 Altium: AIN Isolator
    + Fixed input mode (voltage and current) switch footprint
    [AIn_Isolator.SchDoc]
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2026-01-23 Altium: USB C DFU Connector
    + Fixed the D+ and D- wiring of the USB C DFU connector footprint. Rewired.
    [STM32_MCU.SchDoc]
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2026-02-03 RTC VBAT Fixes
    + Fixes to DS3231 set time function to ensure oscillator remains enabled with loss of main power, to ensure VBAT is used.
    [rtc_ds3231.c]
2026-02-05 I2C PCB Rev. 1 Validation & BMP280 Fixes
    + Validated I2C ISO1540 isolation and BMP280 input register integration
    + Added input and holding register modes for I2C
    + Updated BMP280 read func
    Recommended PCB change: Remove on board field side I2C pull ups to 5V_ISO -> require field user to have external pull ups - this way, 3.3V or 5V sensors can be used (if pulled up on board to 5V_ISO, SCL and SDA will be at 5V on a 3.3V sensor = bad.)
    Pull up should be 4.7K.
    [bmp280.c, ina226.c, main.c]
2026-02-05 Altium: I2C Isolated - Pull ups, TVS
    + Removed field side SDA and SCL pull ups - field user must provide themselves. This allows for 3.3V and 5V field I2C devices to function. (Before, pull ups to 5V_ISO meant SDA and SCL were at 5V, incompatible with 3.3V devices)
    + Added TVS diodes to SDA and SCL field lines.
    [I2C_Isolator.SchDoc]
2026-02-18 Altium: PCB Rev 2 Finalisation
    + Finalising the 2nd revision of the PCB
    + Minor fixes to schematics
    [DOut_Relay.SchDoc, I2C_Isolator.SchDoc, I2C_RTC_DS3231.SchDoc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]
2026-02-18 Factory Reset EStop Clear Fix
    + Bug fixes to ensure EStop configuration is cleared upon factory reset.
    [io_holding_reg.c, io_input_reg.c, main.c]
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

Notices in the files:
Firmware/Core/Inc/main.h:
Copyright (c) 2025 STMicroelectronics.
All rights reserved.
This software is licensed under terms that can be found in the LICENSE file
